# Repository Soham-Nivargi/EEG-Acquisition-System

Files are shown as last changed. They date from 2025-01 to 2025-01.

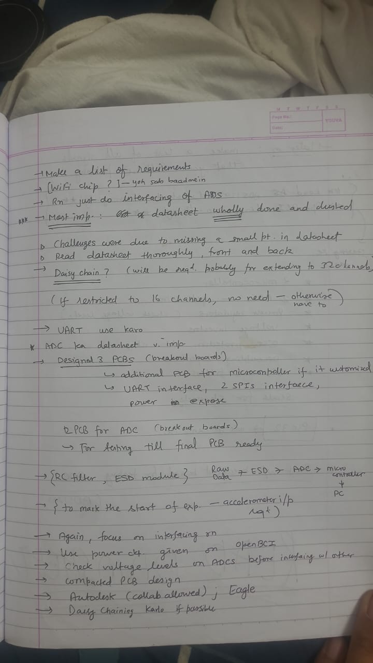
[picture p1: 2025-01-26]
Handwritten Documentation/IMG-20240304-WA0016.jpg

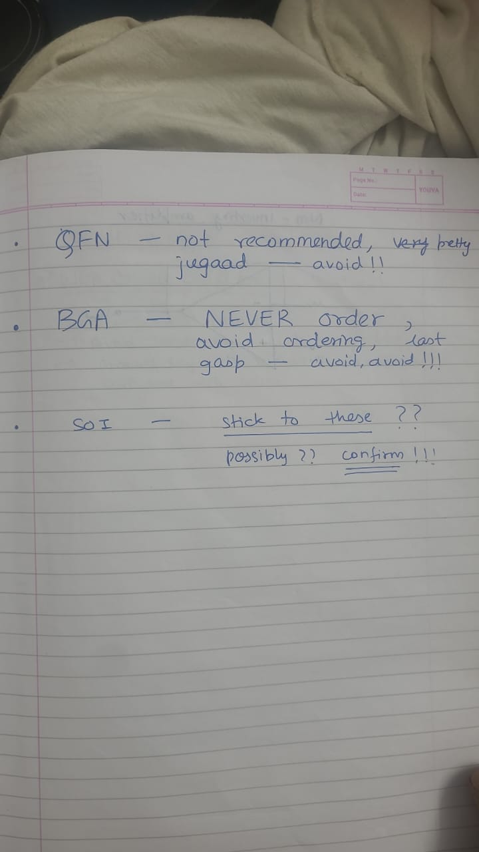
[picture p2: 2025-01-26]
Handwritten Documentation/IMG-20240304-WA0015.jpg

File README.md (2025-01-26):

# EEG-EDL-Project-Grp-14
### _This document describes the file organisation for our project - a 16 channel EEG recording system._
### Original problem statement
Primary objective of the device is to record electroencephalogram (EEG) signals from human brain with high fidelity. EEG acquisition is a non-invasive method of capturing brain signals. The device has two major parts, (a) the recording electrodes (sensors) and (b) the data capture electronics. 
In this work, we will work on developing the electronic system to capture multi-channel EEG. The term "channel" corresponds to number of electrodes (or spatial locations on the brain) that we intend to record. The primary requirement is that of recording fidelity in the presence of numerous noise sources. Noise sources in this context, mainly refers to ambient noise, one of them being the 50 Hz power-line interference. The main constraint is the form-factor of the device. 

Over the course of our project, we were forced to pivot from the original plan.

Thus, these files describe two possible implementations of a 16 channel EEG recording system.

    1. Original Plan : 16 Channels - 2 ADS1299 ICs on a single 4-layer PCB
    2. Modified Plan : 16 Channels - 2 breakout boards, each with 2 layers. Each breakout board having one ADS1299.

The files are organised as follows:

### 1. Main PCB files
   
        A. Main PCB schematic files
        B. Main PCB KiCAD project files (layout)
        
 ### 2. Breakout Board PCB files
   
        A. Breakout board PCB schematic files
        B. Breakout board PCB KiCAD project files (layout)
        C. Breakout board gerber files - for final prototype production
        
 ### 3. Intermediate schematics
   (these are building-block schematics that after being made once could be used with modifications in 
    other PCB schematics)

        A. ADS schematic
        B. ESD schematic
        C. Power Circuit schematic
        D. Bluepill schematic
        
 ### 4. Preprocessing and testing
 
        A. Code files for testing
        B. Text files with output of testing

 ### 5. Symbols and footprints 
   (contains the downloaded footprints and symbols used by us in the schematics)

 ### 6.Handwritten documentation
   (analysis of datasheets, lecture notes, discussion with professors and seniors)

 ### 7. CAD files
   (Files for 3D printing the outer casing/asssembly for our interfaced PCB)

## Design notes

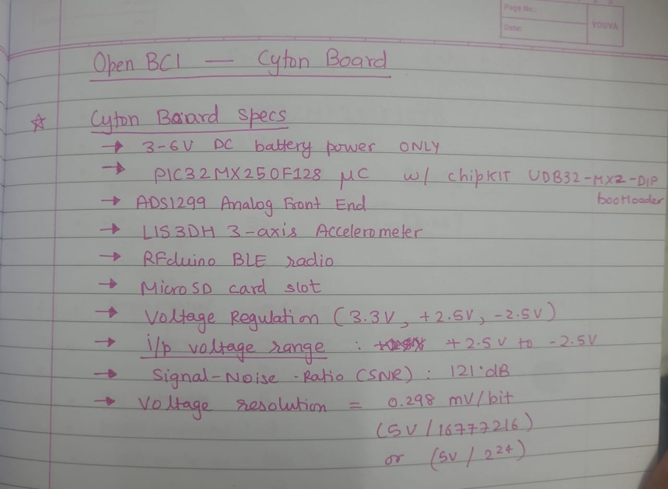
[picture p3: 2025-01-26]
Handwritten Documentation/IMG-20240304-WA0013.jpg

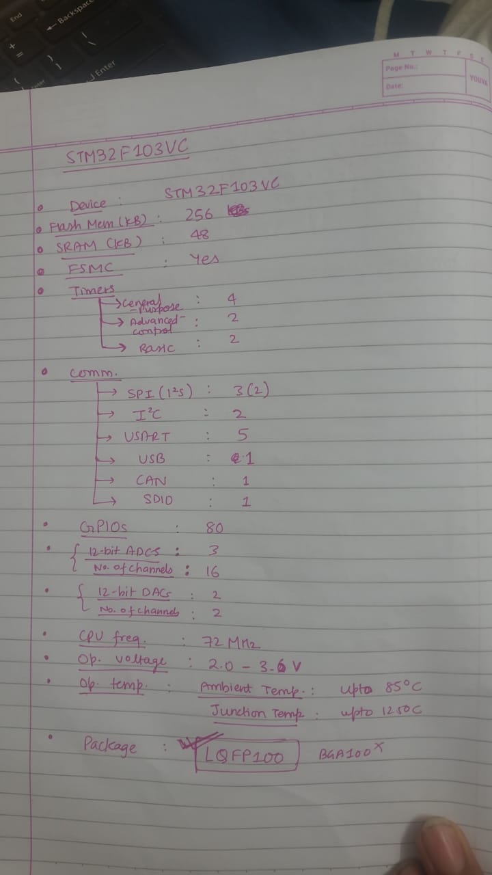
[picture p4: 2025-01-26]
Handwritten Documentation/IMG-20240304-WA0017.jpg

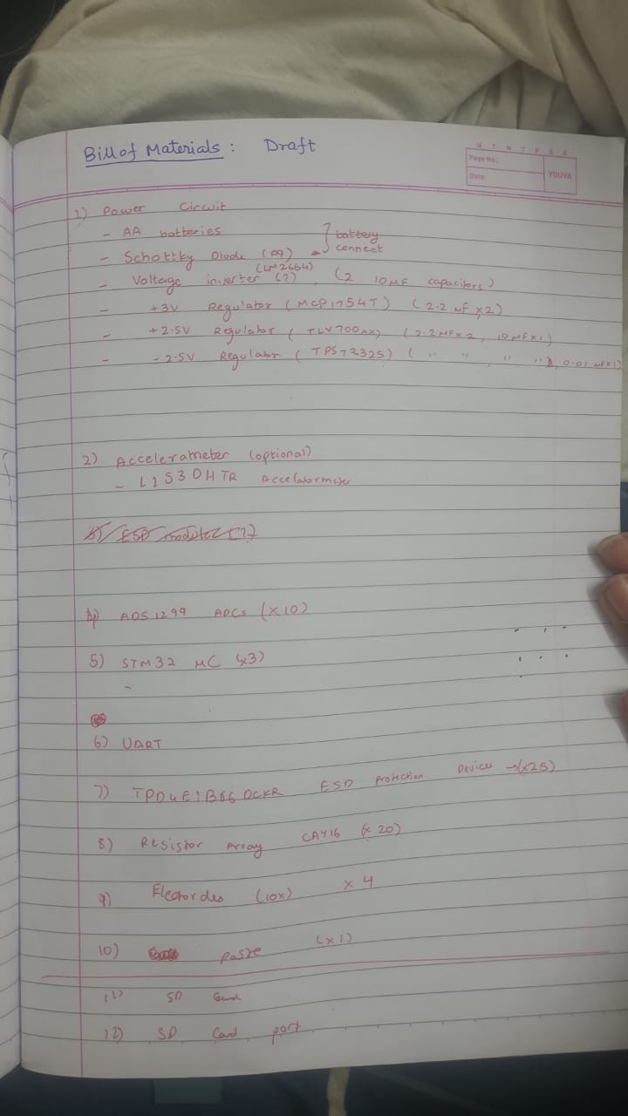
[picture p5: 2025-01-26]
Handwritten Documentation/IMG-20240304-WA0020.jpg

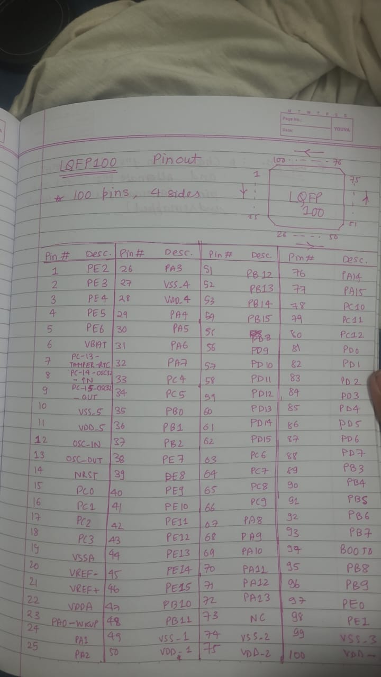
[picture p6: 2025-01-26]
Handwritten Documentation/IMG-20240304-WA0014.jpg

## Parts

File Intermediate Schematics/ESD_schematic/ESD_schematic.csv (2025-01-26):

Source: | C:\Users\91999\Downloads\hello\wien_bridge_oscillator\ESD_schematic\ESD_schematic.kicad_sch
Date: | 12-02-2024 16:13:50
Tool: | Eeschema 7.0.10
Generator: | C:\Program Files\KiCad\7.0\bin\scripting\plugins/bom_csv_grouped_by_value_with_fp.py
Component Count: | 16
Ref | Qnty | Value | Cmp name | Footprint | Description | Vendor | DNP
C1, C2, C3, C4, C6 | 5 | CKCL44X7R1H102M085AA | CKCL44X7R1H102M085AA | CKCL44X7R1H102M085AA:CAPCAF50P200X125X85-8
D1, D2, D3, D4, D5, D6 | 6 | TPD4E1B06DCKR | TPD4E1B06DCKR | TPD4E1B06DCKR:TVS_TPD4E1B06DCKR
R1, R2, R3, R4, R6 | 5 | CAY16-2201F4LF | CAY16-2201F4LF | CAY16_BRN

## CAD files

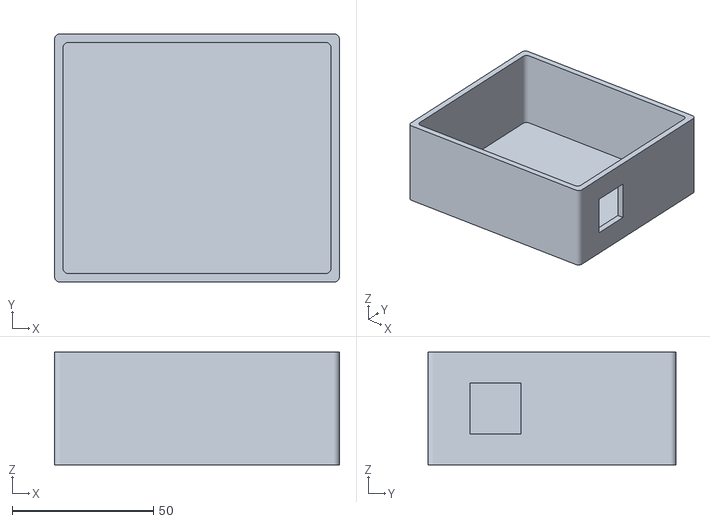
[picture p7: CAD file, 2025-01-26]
CAD files/edl_box.stl
101.0 x 88.0 x 40.0

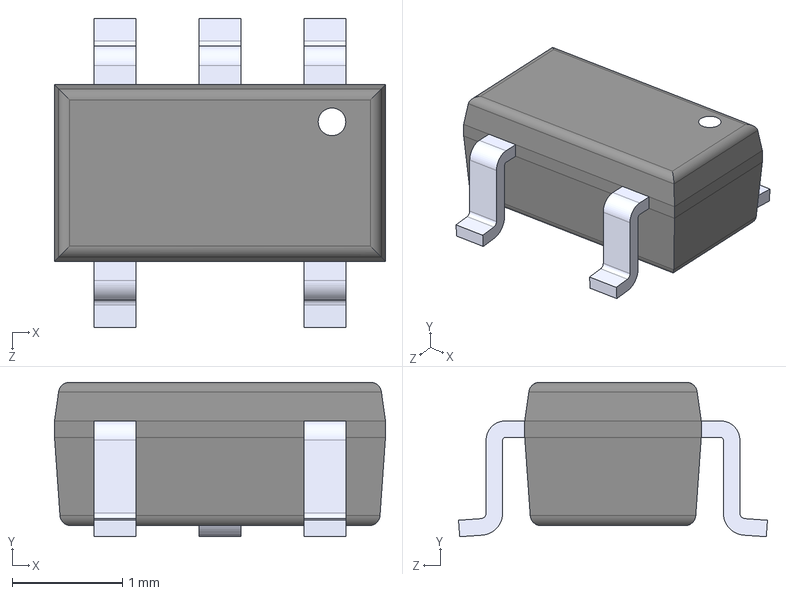
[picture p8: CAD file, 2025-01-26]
symbols_and_footprints/AP2112K - 3.3/AP2112K-3.3TRG1.step
3.00 x 1.40 x 2.80 mm

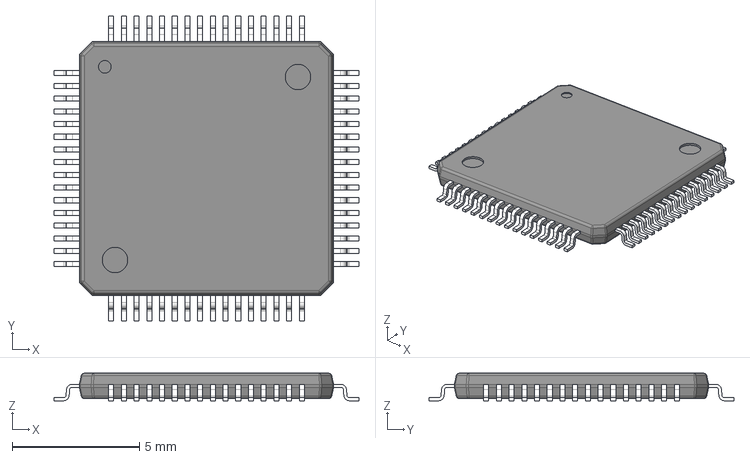
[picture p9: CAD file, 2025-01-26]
symbols_and_footprints/LIB_ADS1299IPAG/ADS1299IPAG/3D/ADS1299IPAG.stp
12.0 x 12.0 x 1.09 mm
BODY_VEC64A
LEAD_VEC64A x 64

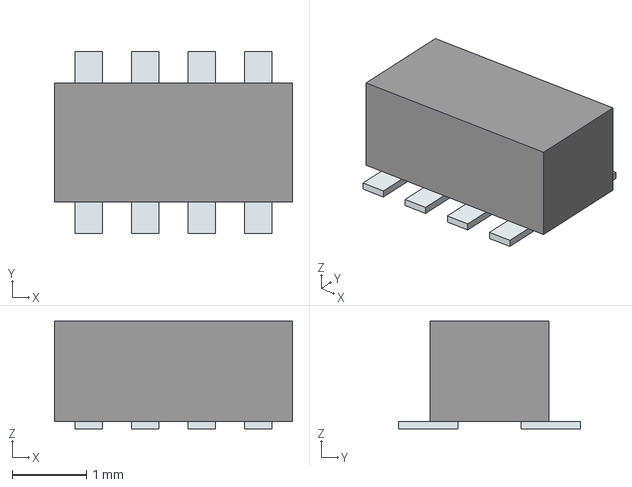
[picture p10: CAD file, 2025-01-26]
symbols_and_footprints/LIB_W3A41C102MAT2A/W3A41C102MAT2A/3D/W3A41C102MAT2A.stp
3.20 x 2.45 x 1.45 mm
Pins

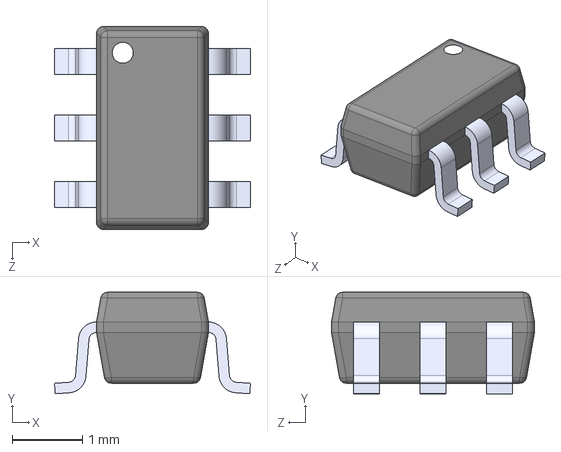
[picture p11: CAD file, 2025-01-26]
symbols_and_footprints/lm2665/LM2665M6.step
2.80 x 1.45 x 2.90 mm

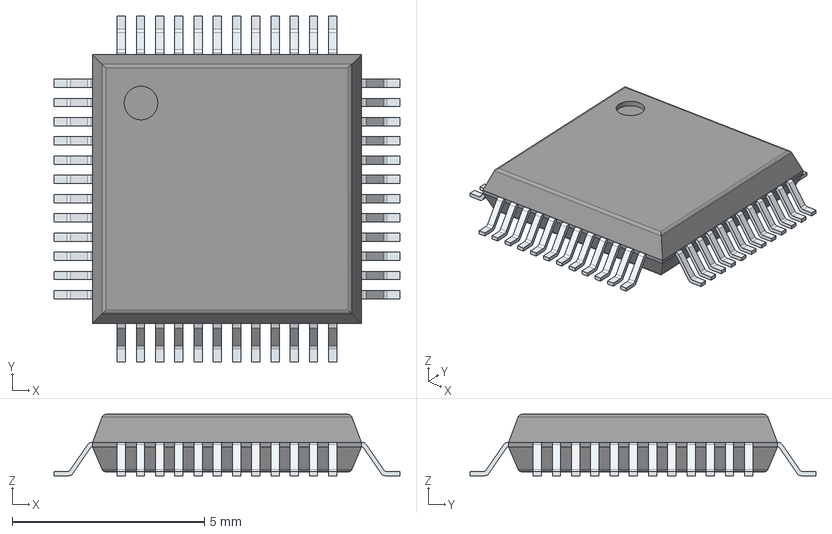
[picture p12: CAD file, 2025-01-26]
symbols_and_footprints/stm32/STM32F103C8T6TR/3D/STM32F103C8T6TR.stp
9.00 x 9.00 x 1.60 mm
PinsArrayLR
PinsArrayTB

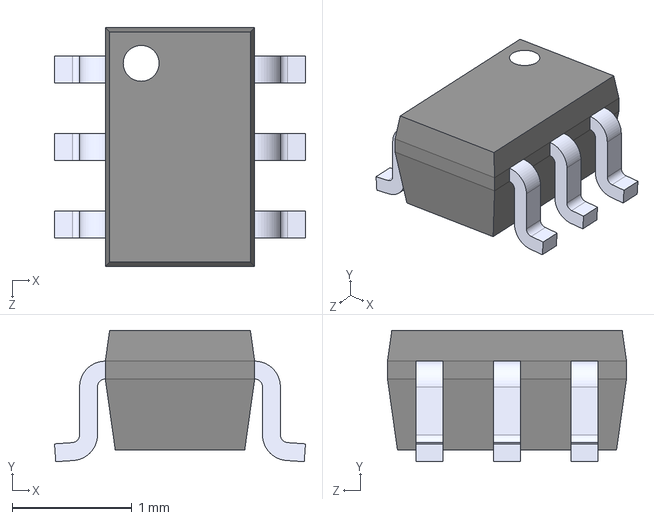
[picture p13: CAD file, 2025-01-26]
symbols_and_footprints/TPD4E1B06DCKR/TPD4E1B06DCKR.step
2.10 x 1.10 x 2.00 mm

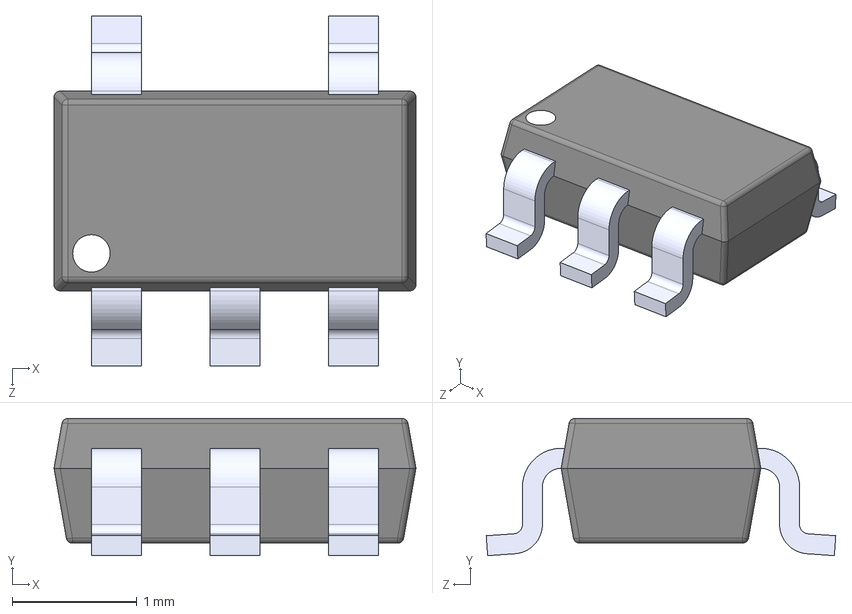
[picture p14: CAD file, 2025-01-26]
symbols_and_footprints/tlv/TLV70025QDDCRQ1.step
2.90 x 1.10 x 2.80 mm

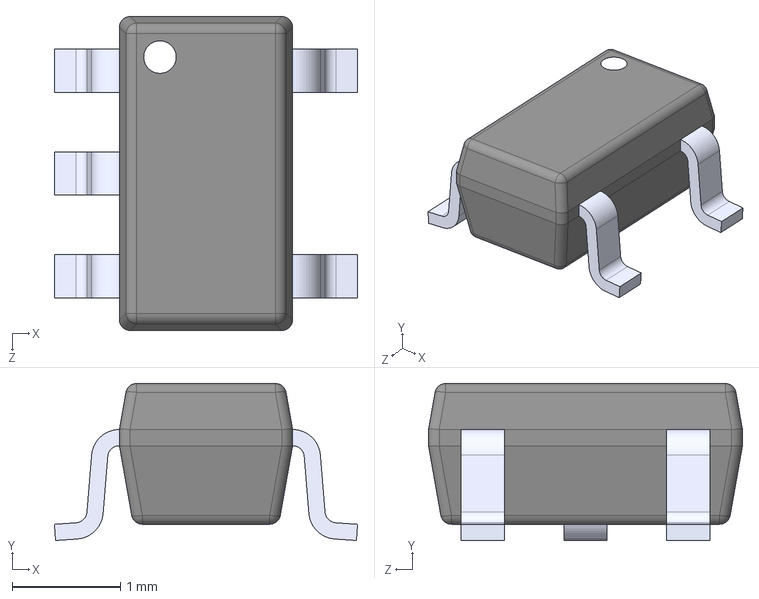
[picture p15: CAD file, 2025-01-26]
symbols_and_footprints/tps/TPS72325DBVR.step
2.80 x 1.45 x 2.90 mm

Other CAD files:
CAD files/Edl_box_.f3d
symbols_and_footprints/LIB_ADS1299IPAG/ADS1299IPAG/Allegro/qfp50p1200x1200x120-64n.psm
symbols_and_footprints/LIB_ADS1299IPAG/ADS1299IPAG/DEHDL/ads1299ipag/chips/chips.prt
symbols_and_footprints/LIB_W3A41C102MAT2A/W3A41C102MAT2A/Allegro/w3a41c102mat2a.psm
symbols_and_footprints/LIB_W3A41C102MAT2A/W3A41C102MAT2A/DEHDL/w3a41c102mat2a/chips/chips.prt
symbols_and_footprints/stm32/STM32F103C8T6TR/Allegro/qfp50p900x900x160-48n.psm
symbols_and_footprints/stm32/STM32F103C8T6TR/DEHDL/stm32f103c8t6tr/chips/chips.prt

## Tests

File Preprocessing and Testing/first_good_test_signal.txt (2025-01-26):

success12582912
81419
81596
80953
81358
81363
81739
81523
81789
success12582912
82603
82718
82394
82581
82616
82764
82656
82817
success12582912
0
8388608
8388607
8388608
8388608
0
8388608
8388608
success12582912
0
1240512
0
18
15581184
0
4845
12582912
success12582912
0
933263
8388607
9377830
0
6940615
0
8388607
success12582912
0
226513
8388607
8388608
0
13741152
0
8388607
success12582912
0
250813
8388607
8388608
0
8448695
0
8388607
success12582912
0
219410
8388607
8388608
0
8388608
0
8388607
success12582912
0
183473
8388607
8388608
0
8388608
0
8174129
success12582912
0
258539
8388607
8388608
0
8388608
0
8388607
success12582912
0
165614
8388607
8388608
0
8388608
0
8388607
success12582912
0
206816
8388607
8388800
0
3
5355391
16777088
success12582912
0
222820
8388607
8388608
0
8388608
0
8388607
success12582912
0
16648719
15887814
31836
0
16661664
0
16665404
success12582912
0
16635995
15912704
29484
0
16659882
0
16664634
success12582912
0
16641954
15906739
30159
0
16660508
0
16665207
success12582912
0
16641445
15893398
36709
0
16660210
0
16664487
success12582912
0
16650290
15898451
28247
0
16660212
0
16664377
success12582912
0
16644265
15925133
28248
0
16660806
0
16664036
success12582912
0
16635498
15923364
47761
0
16660495
0
16663225
success12582912
0
16651787
15897388
29521
0
16661507
0
16664712
success12582912
0
16647909
15861555
36088
0
16661229
0
16665673
success12582912
1382
134984
16747130
16776127
16745243
16756230
16752920
16756185
success12582922
6096
132765
16745592
0
101774
0
0
0

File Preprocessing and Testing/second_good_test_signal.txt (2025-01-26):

success12582912
81105
81345
80621
81079
81073
81491
81244
81557
success12582913
82600
82714
82401
82589
82623
82762
82652
12582913
success29360129
8388608
8388608
0
0
8388607
0
8388608
8388608
success12582912
81325
81554
80859
81289
81289
81694
81426
114688
success12582912
82618
82714
82394
82585
82623
82761
82654
114688
success12582912
98826
297766
0
14604
16629830
0
16660574
16647447
success12582912
81297
81495
80838
81234
81248
81656
81418
81692
success12582912
82546
82664
82356
82534
82572
82724
82606
82768
success12582912
82546
82664
82356
82534
82572
82724
82606
82768
success12582912
82546
82664
82356
82534
82572
82724
82606
82768
success12582912
82546
82664
82356
82534
82572
82724
82606
82768
success12582912
82546
82664
82356
82534
82572
82724
82606
82768
success12582912
82546
82664
82356
82534
82572
82724
82606
82768
success12582912
82546
82664
82356
82534
82572
82724
82606
82768
success12582912
82546
82664
82356
82534
82572
82724
82606
82768
success12582912
81340
81548
80891
81315
81313
81683
114688
317
success12582912
82603
82711
82406
82590
82633
82758
82664
82798
success12582912
0
8388608
8388607
8388608
8388608
0
8388608
8388608
success12582912
0
8388608
8388607
8388607
0
0
8388608
8388608
success12582912
0
8388608
8388607
8388607
0
0
8388608
8388608
success12582912
0
8388608
8388607
8388607
0
0
8388608
8388608
success12582912
0
12582912
0
8388608
8388607
8388607
0
0
success12582912
0
8388608
8388607
8388607
0
0
8388608
8388608
success12582912
0
8388608
8388607
8388607
0
0
8388608
8388608
success12632064
0
32768
32767
16744447
16711680
0
32768
32768
success12582912
0
8388608
8388607
8388607
0
0
8388608
8388608
success12582912
0
8388608
8387584
0
2048
2047
16775167
16773120
success12582912
8435
137108
16746079
16769675
16745474
16755648
16752532
16756418
success12582912
2081
131258
16746168
222
16745385
16756163
16752756
16756782
success12582912
9726
146843
16747320
4938
16745470
16755956
16752775
16756490
success12582912
11093
180224
15
7406088
14221187
9175007
8060803
4194220
success12582912
8449
205087
19940
624
16632658
16696934
16659447
16650415
success12582912
11593
229088
18304
1698
16632067
16696850
16659174
16649977
success12582912
4031
128496
16745359
16770377
16745504
16755925
16752667
16756270
success12582912
1609
138244
16745455
16774399
16745374
16756159
16752659
16760832
success12582912
50491
245760
194
10420967
15007796
8323197
1474559
16740717
success12582912
47397
184217
3504
23639
8388607
7433478
0
16754759
success12582912
51818
191748
6921
29670
8388607
7433491
49152
0

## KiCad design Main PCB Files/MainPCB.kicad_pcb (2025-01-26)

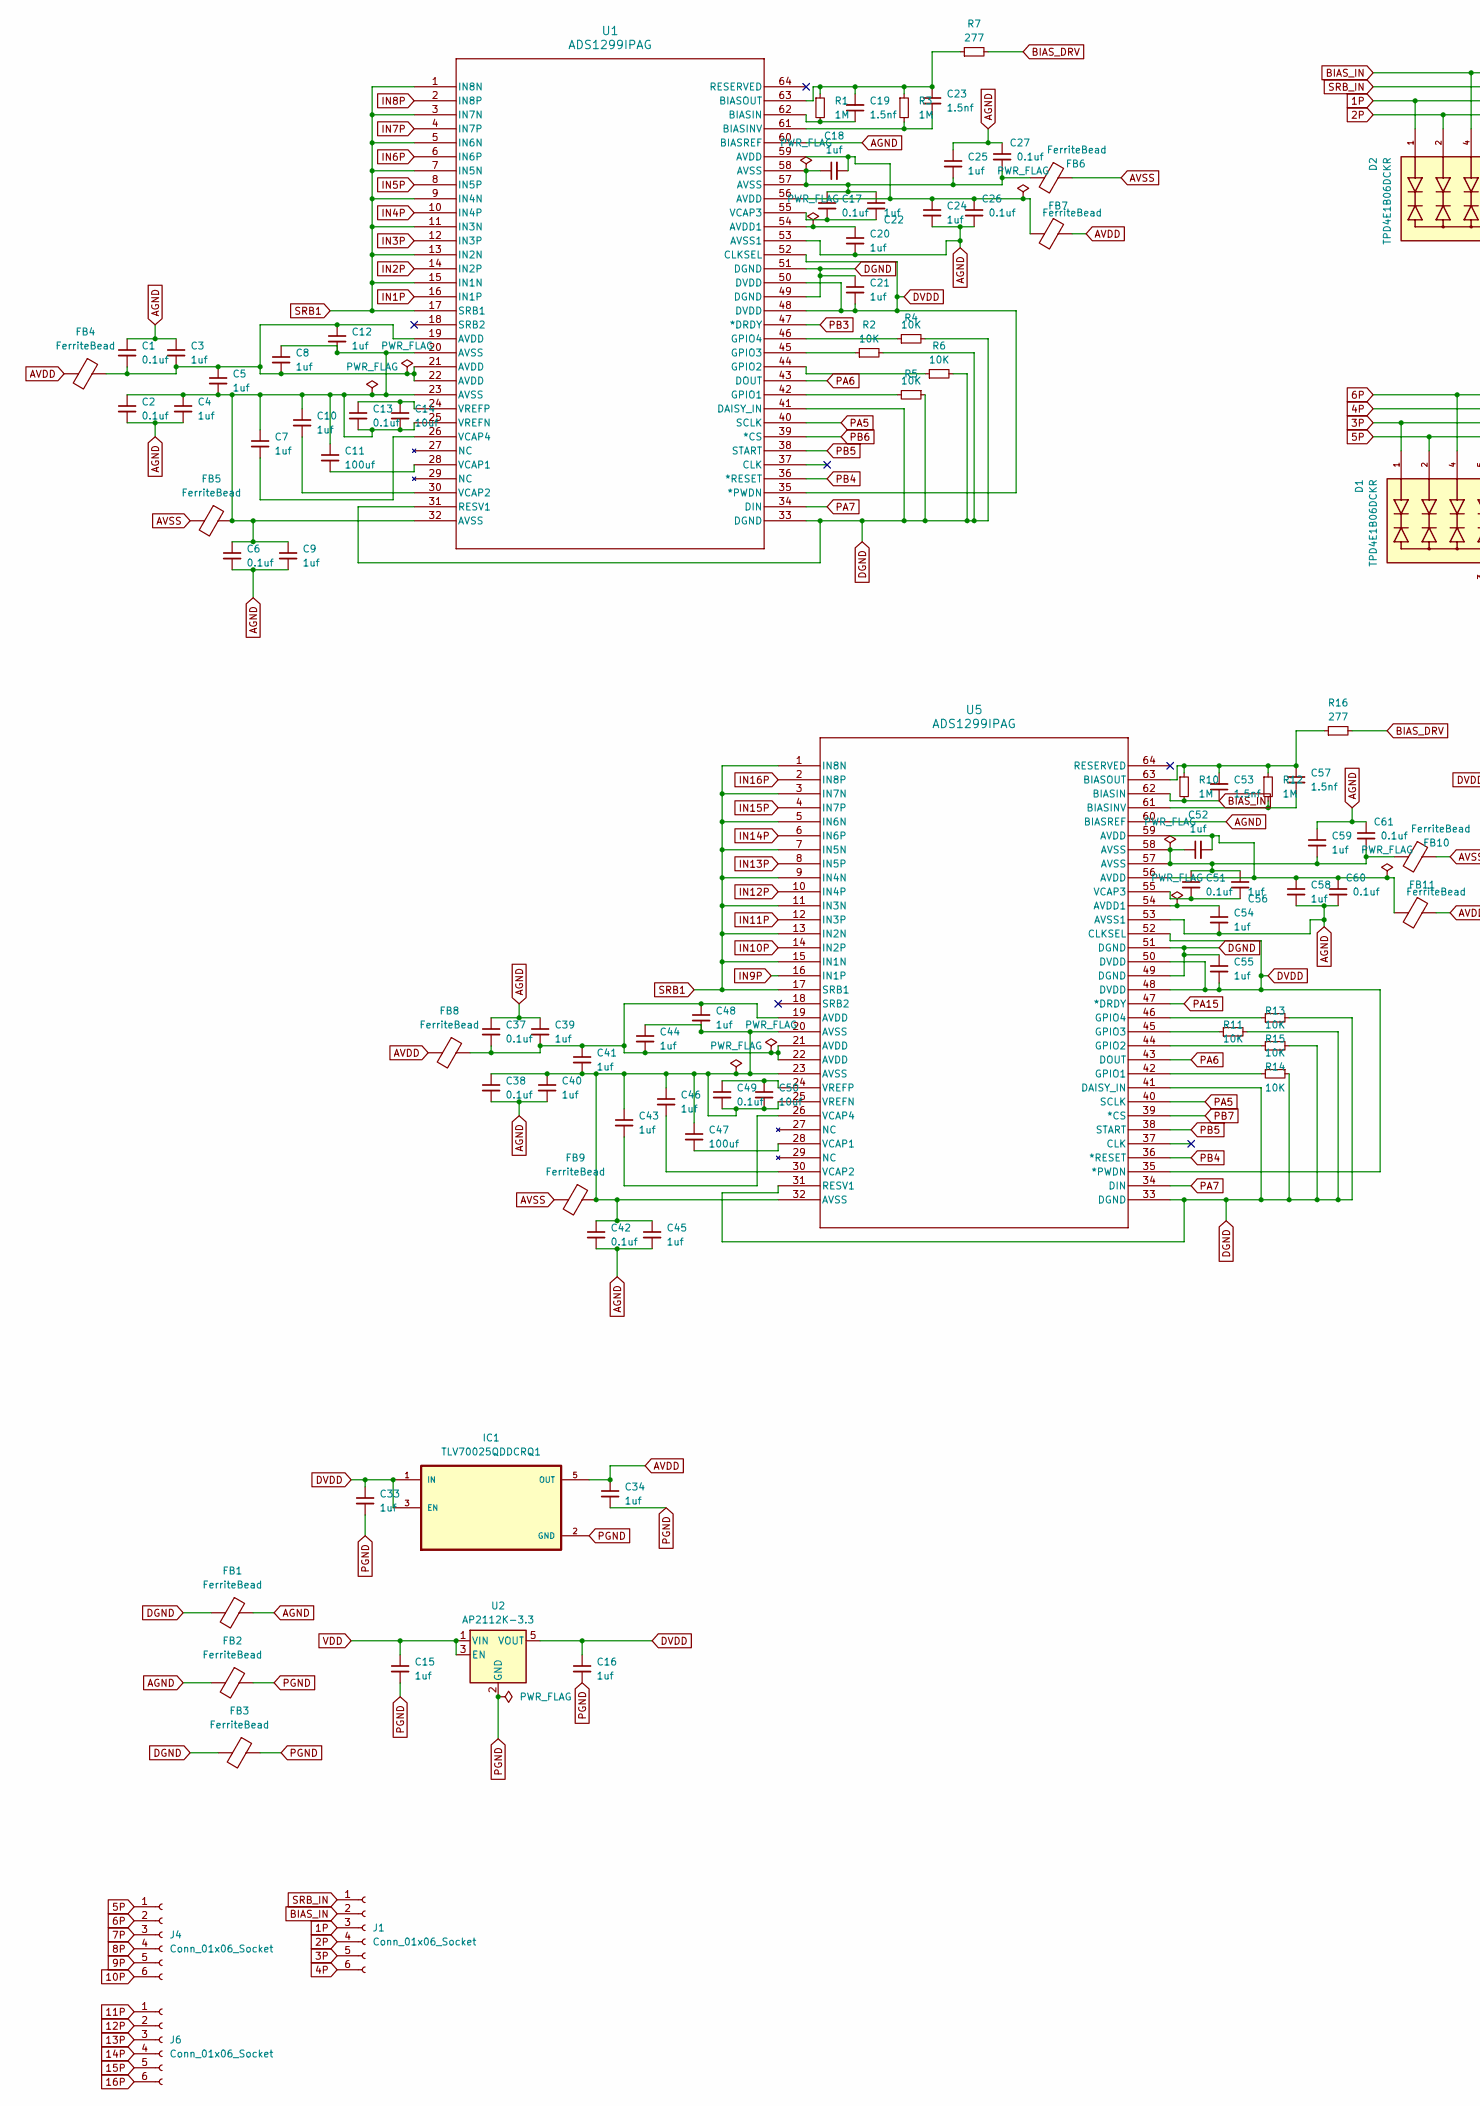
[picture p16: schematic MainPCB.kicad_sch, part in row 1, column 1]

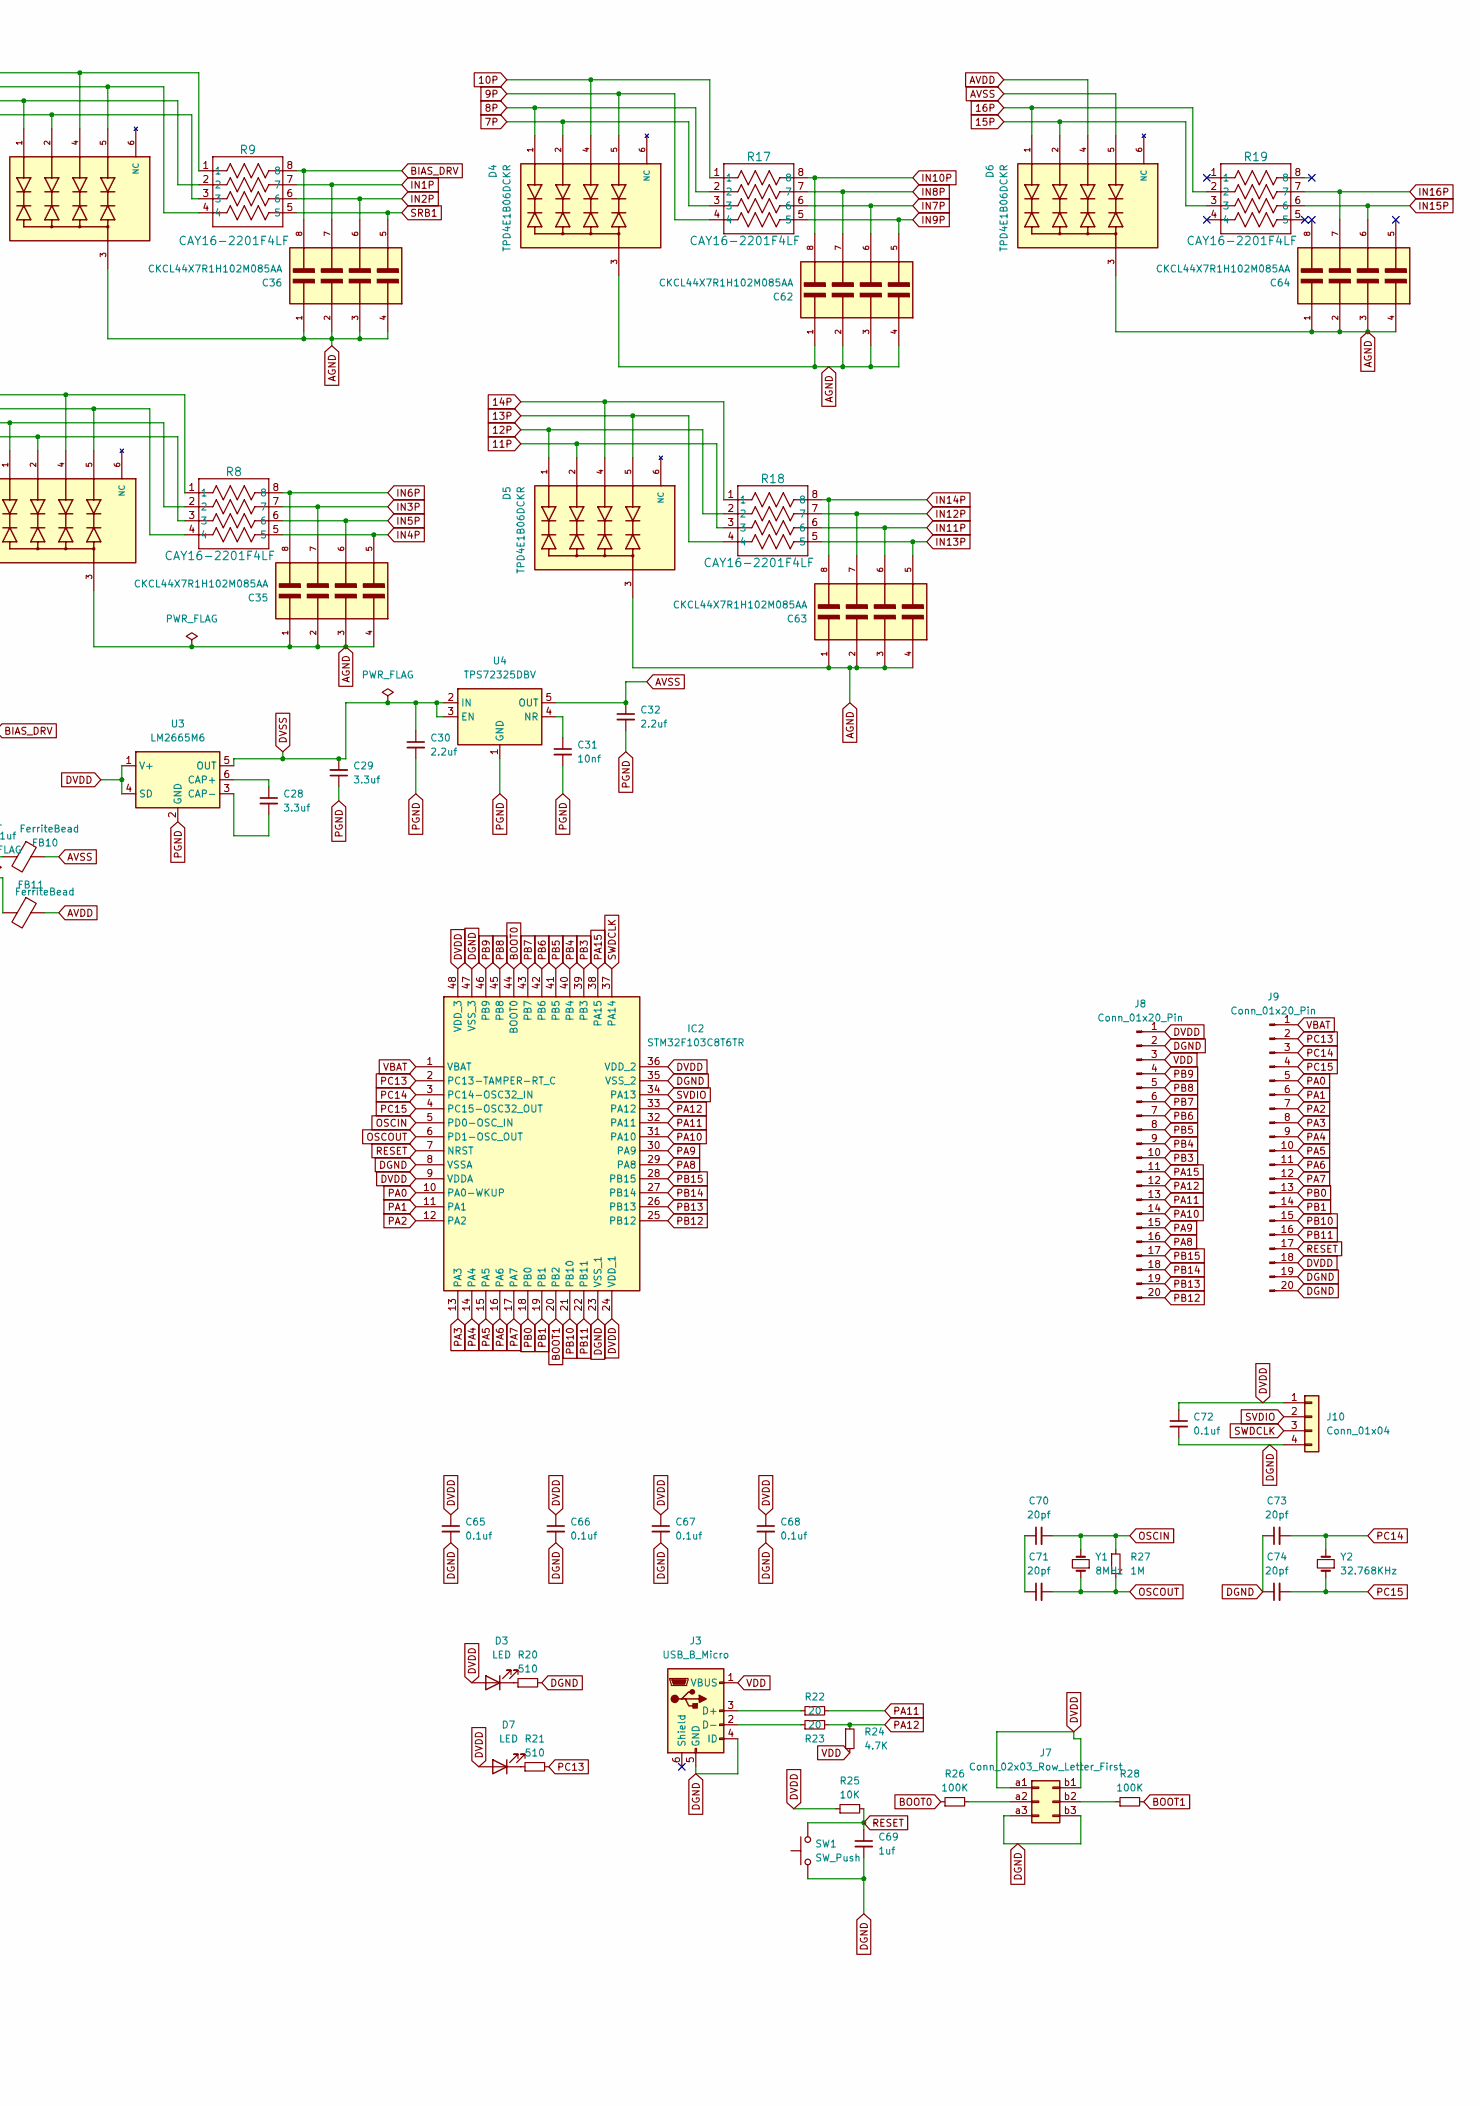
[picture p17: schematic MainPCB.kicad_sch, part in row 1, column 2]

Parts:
C1, C2, C6, C13, C17, C26, C27, C37, C38, C42, C49, C51, C60, C61, C65, C66, C67, C68, C72: 0.1uf; C_0603_1608Metric_Pad1.08x0.95mm_HandSolder
C3, C4, C5, C7, C8, C9, C10, C12, C15, C16, C18, C20, C21, C22, C24, C25, C33, C34, C39, C40, C41, C43, C44, C45, C46, C48, C52, C54, C55, C56, C58, C59, C69: 1uf; C_0603_1608Metric_Pad1.08x0.95mm_HandSolder
C11, C47: 100uf; C_1206_3216Metric_Pad1.33x1.80mm_HandSolder
C14, C50: 10uf; CP_EIA-3216-18_Kemet-A_Pad1.58x1.35mm_HandSolder
C19, C23, C53, C57: 1.5nf; C_0603_1608Metric_Pad1.08x0.95mm_HandSolder
C28, C29: 3.3uf; CP_EIA-3216-18_Kemet-A_Pad1.58x1.35mm_HandSolder
C30, C32: 2.2uf; C_0603_1608Metric_Pad1.08x0.95mm_HandSolder
C31: 10nf; C_0603_1608Metric_Pad1.08x0.95mm_HandSolder
C35, C36, C62, C63, C64: CKCL44X7R1H102M085AA; W3A41C102MAT2A; PARTREV Dec 2014
C70, C71, C73, C74: 20pf; C_0603_1608Metric_Pad1.08x0.95mm_HandSolder
D1, D2, D4, D5, D6: TPD4E1B06DCKR; TVS_TPD4E1B06DCKR; PARTREV C
D3, D7: LED; LED_0402_1005Metric_Pad0.77x0.64mm_HandSolder
FB1, FB2, FB3, FB4, FB5, FB6, FB7, FB8, FB9, FB10, FB11: FerriteBead; L_0603_1608Metric_Pad1.05x0.95mm_HandSolder
IC1: TLV70025QDDCRQ1; SOT95P280X110-5N
IC2: STM32F103C8T6TR; QFP50P900X900X160-48N; Mouser Part Number 511-STM32F103C8T6TR
J1, J4, J6: Conn_01x06_Socket; PinSocket_1x06_P2.54mm_Vertical
J3: USB_B_Micro; USB_Micro-B_Molex_47346-0001
J7: Conn_02x03_Row_Letter_First; PinHeader_2x03_P2.54mm_Vertical
J8, J9: Conn_01x20_Pin; PinHeader_1x20_P2.54mm_Vertical
J10: Conn_01x04; PinHeader_1x04_P2.54mm_Vertical
R1, R3, R10, R12, R27: 1M; R_0603_1608Metric_Pad0.98x0.95mm_HandSolder
R2, R4, R5, R6, R11, R13, R14, R15, R25: 10K; R_0603_1608Metric_Pad0.98x0.95mm_HandSolder
R7, R16: 277; R_0603_1608Metric_Pad0.98x0.95mm_HandSolder
R8, R9, R17, R18, R19: CAY16-2201F4LF; CAY16_BRN
R20, R21: 510; R_0603_1608Metric_Pad0.98x0.95mm_HandSolder
R22, R23: 20; R_0603_1608Metric_Pad0.98x0.95mm_HandSolder
R24: 4.7K; R_0603_1608Metric_Pad0.98x0.95mm_HandSolder
R26, R28: 100K; R_0603_1608Metric_Pad0.98x0.95mm_HandSolder
SW1: SW_Push; SW_SPST_TL3342
U1, U5: ADS1299IPAG; QFP50P1200X1200X120-64N
U2: AP2112K-3.3; SOT95P285X140-5N
U3: LM2665M6; SOT95P280X145-6N
U4: TPS72325DBV; SOT95P280X145-5N
Y1: 8MHz; Crystal_HC50_Vertical
Y2: 32.768KHz; 830016178

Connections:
1P: D2.1, J1.3, R9.2
2P: D2.2, J1.4, R9.3
3P: D1.1, J1.5, R8.2
4P: D1.5, J1.6, R8.4
5P: D1.2, J4.1, R8.3
6P: D1.4, J4.2, R8.1
7P: D4.2, J4.3, R17.3
8P: D4.1, J4.4, R17.2
9P: D4.5, J4.5, R17.4
10P: D4.4, J4.6, R17.1
11P: D5.2, J6.1, R18.3
12P: D5.1, J6.2, R18.2
13P: D5.5, J6.3, R18.4
14P: D5.4, J6.4, R18.1
15P: D6.2, J6.5, R19.3
16P: D6.1, J6.6, R19.2
AGND: C1.1, C2.2, C3.1, C4.2, C6.2, C9.2, C20.2, C24.2, C25.1, C26.2, C27.1, C35.1, C35.2, C35.3, C35.4, C36.1, C36.2, C36.3, C36.4, C37.1, C38.2, C39.1, C40.2, C42.2, C45.2, C54.2, C58.2, C59.1, C60.2, C61.1, C62.1, C62.2, C62.3, C62.4, C63.1, C63.2, C63.3, C63.4, C64.1, C64.2, C64.3, C64.4, D1.3, D2.3, D4.3, D5.3, D6.3, FB1.1, FB2.2, U1.53 (AVSS1), U1.60 (BIASREF), U5.53 (AVSS1), U5.60 (BIASREF)
AVDD: C34.1, D6.4, FB4.2, FB7.1, FB8.2, FB11.1, IC1.5 (OUT)
AVSS: C32.1, D6.5, FB5.2, FB6.1, FB9.2, FB10.1, U4.5 (OUT)
BIAS_DRV: C36.8, R7.2, R9.8, R16.2
BIAS_IN: C53.1, D2.4, J1.2, R9.1, R10.2, U5.62 (BIASIN)
BOOT0: IC2.44 (BOOT0), R26.1
BOOT1: IC2.20 (PB2), R28.2
DGND: C21.1, C55.1, C65.2, C66.2, C67.2, C68.2, C69.2, C72.2, C73.1, C74.1, FB1.2, FB3.2, IC2.8 (VSSA), IC2.23 (VSS_1), IC2.35 (VSS_2), IC2.47 (VSS_3), J3.4 (ID), J3.5 (GND), J7.a3, J7.b3, J8.2, J9.19, J9.20, J10.4, R2.2, R4.2, R5.1, R6.2, R11.2, R13.2, R14.1, R15.2, R20.2, SW1.1, U1.31 (RESV1), U1.33 (DGND), U1.41 (DAISY_IN), U1.49 (DGND), U1.51 (DGND), U5.31 (RESV1), U5.33 (DGND), U5.41 (DAISY_IN), U5.49 (DGND), U5.51 (DGND)
DVDD: C16.1, C21.2, C33.1, C55.2, C65.1, C66.1, C67.1, C68.1, C72.1, D3.2 (A), D7.2 (A), IC1.1 (IN), IC1.3 (EN), IC2.9 (VDDA), IC2.24 (VDD_1), IC2.36 (VDD_2), IC2.48 (VDD_3), J7.a1, J7.b1, J8.1, J9.18, J10.1, R25.1, U1.35 (*PWDN), U1.48 (DVDD), U1.50 (DVDD), U1.52 (CLKSEL), U2.5 (VOUT), U3.1 (V+), U3.4 (SD), U5.35 (*PWDN), U5.48 (DVDD), U5.50 (DVDD), U5.52 (CLKSEL)
DVSS: C29.2, C30.1, U3.5 (OUT), U4.2 (IN), U4.3 (EN)
IN1P: C36.7, R9.7, U1.16 (IN1P)
IN2P: C36.6, R9.6, U1.14 (IN2P)
IN3P: C35.7, R8.7, U1.12 (IN3P)
IN4P: C35.5, R8.5, U1.10 (IN4P)
IN5P: C35.6, R8.6, U1.8 (IN5P)
IN6P: C35.8, R8.8, U1.6 (IN6P)
IN7P: C62.6, R17.6, U1.4 (IN7P)
IN8P: C62.7, R17.7, U1.2 (IN8P)
IN9P: C62.5, R17.5, U5.16 (IN1P)
IN10P: C62.8, R17.8, U5.14 (IN2P)
IN11P: C63.6, R18.6, U5.12 (IN3P)
IN12P: C63.7, R18.7, U5.10 (IN4P)
IN13P: C63.5, R18.5, U5.8 (IN5P)
IN14P: C63.8, R18.8, U5.6 (IN6P)
IN15P: C64.6, R19.6, U5.4 (IN7P)
IN16P: C64.7, R19.7, U5.2 (IN8P)
unnamed: C1.2, C3.2, C5.1, C8.2, C12.1, FB4.1, U1.19 (AVDD), U1.21 (AVDD), U1.22 (AVDD)
unnamed: C17.1, C18.1, C22.1, C25.2, C27.2, FB6.2, U1.57 (AVSS), U1.58 (AVSS)
unnamed: C18.2, C24.1, C26.1, FB7.2, U1.56 (AVDD), U1.59 (AVDD)
unnamed: C37.2, C39.2, C41.1, C44.2, C48.1, FB8.1, U5.19 (AVDD), U5.21 (AVDD), U5.22 (AVDD)
unnamed: C51.1, C52.1, C56.1, C59.2, C61.2, FB10.2, U5.57 (AVSS), U5.58 (AVSS)
unnamed: C52.2, C58.1, C60.1, FB11.2, U5.56 (AVDD), U5.59 (AVDD)
unnamed: C70.1, C71.1
unnamed: D3.1 (K), R20.1
unnamed: D7.1 (K), R21.1
unnamed: J3.3 (D+), R22.1
unnamed: J3.2 (D-), R23.1
unnamed: J7.a2, R26.2
unnamed: J7.b2, R28.1
unnamed: C20.1, U1.54 (AVDD1)
unnamed: C19.1, R1.2, U1.62 (BIASIN)
unnamed: C23.2, R3.2, U1.61 (BIASINV)
unnamed: C19.2, C23.1, R1.1, R3.1, R7.1, U1.63 (BIASOUT)
unnamed: R5.2, U1.42 (GPIO1)
unnamed: R6.1, U1.44 (GPIO2)
unnamed: R2.1, U1.45 (GPIO3)
unnamed: R4.1, U1.46 (GPIO4)
unnamed: C11.2, U1.28 (VCAP1)
unnamed: C10.2, U1.30 (VCAP2)
unnamed: C17.2, C22.2, U1.55 (VCAP3)
unnamed: C7.2, U1.26 (VCAP4)
unnamed: C2.1, C4.1, C5.2, C6.1, C7.1, C8.1, C9.1, C10.1, C11.1, C12.2, C13.2, C14.2, FB5.1, U1.20 (AVSS), U1.23 (AVSS), U1.25 (VREFN), U1.32 (AVSS)
unnamed: C13.1, C14.1, U1.24 (VREFP)
unnamed: C28.1, U3.6 (CAP+)
unnamed: C28.2, U3.3 (CAP-)
unnamed: C31.1, U4.4 (NR)
unnamed: C54.1, U5.54 (AVDD1)
unnamed: C57.2, R12.2, U5.61 (BIASINV)
unnamed: C53.2, C57.1, R10.1, R12.1, R16.1, U5.63 (BIASOUT)
unnamed: R14.2, U5.42 (GPIO1)
unnamed: R15.1, U5.44 (GPIO2)
unnamed: R11.1, U5.45 (GPIO3)
unnamed: R13.1, U5.46 (GPIO4)
unnamed: C47.2, U5.28 (VCAP1)
unnamed: C46.2, U5.30 (VCAP2)
unnamed: C51.2, C56.2, U5.55 (VCAP3)
unnamed: C43.2, U5.26 (VCAP4)
unnamed: C38.1, C40.1, C41.2, C42.1, C43.1, C44.1, C45.1, C46.1, C47.1, C48.2, C49.2, C50.2, FB9.1, U5.20 (AVSS), U5.23 (AVSS), U5.25 (VREFN), U5.32 (AVSS)
unnamed: C49.1, C50.1, U5.24 (VREFP)
OSCIN: C70.2, IC2.5 (PD0-OSC_IN), R27.1, Y1.2
OSCOUT: C71.2, IC2.6 (PD1-OSC_OUT), R27.2, Y1.1
PA0: IC2.10 (PA0-WKUP), J9.5
PA1: IC2.11 (PA1), J9.6
PA2: IC2.12 (PA2), J9.7
PA3: IC2.13 (PA3), J9.8
PA4: IC2.14 (PA4), J9.9
PA5: IC2.15 (PA5), J9.10, U1.40 (SCLK), U5.40 (SCLK)
PA6: IC2.16 (PA6), J9.11, U1.43 (DOUT), U5.43 (DOUT)
PA7: IC2.17 (PA7), J9.12, U1.34 (DIN), U5.34 (DIN)
PA8: IC2.29 (PA8), J8.16
PA9: IC2.30 (PA9), J8.15
PA10: IC2.31 (PA10), J8.14
PA11: IC2.32 (PA11), J8.13, R22.2
PA12: IC2.33 (PA12), J8.12, R23.2, R24.1
PA15: IC2.38 (PA15), J8.11, U5.47 (*DRDY)
PB0: IC2.18 (PB0), J9.13
PB1: IC2.19 (PB1), J9.14
PB3: IC2.39 (PB3), J8.10, U1.47 (*DRDY)
PB4: IC2.40 (PB4), J8.9, U1.36 (*RESET), U5.36 (*RESET)
PB5: IC2.41 (PB5), J8.8, U1.38 (START), U5.38 (START)
PB6: IC2.42 (PB6), J8.7, U1.39 (*CS)
PB7: IC2.43 (PB7), J8.6, U5.39 (*CS)
PB8: IC2.45 (PB8), J8.5
PB9: IC2.46 (PB9), J8.4
PB10: IC2.21 (PB10), J9.15
PB11: IC2.22 (PB11), J9.16
PB12: IC2.25 (PB12), J8.20
PB13: IC2.26 (PB13), J8.19
PB14: IC2.27 (PB14), J8.18
PB15: IC2.28 (PB15), J8.17
PC13: IC2.2 (PC13-TAMPER-RT_C), J9.2, R21.2
PC14: C73.2, IC2.3 (PC14-OSC32_IN), J9.3, Y2.2
PC15: C74.2, IC2.4 (PC15-OSC32_OUT), J9.4, Y2.1
PGND: C15.2, C16.2, C29.1, C30.2, C31.2, C32.2, C33.2, C34.2, FB2.1, FB3.1, IC1.2 (GND), U2.2 (GND), U3.2 (GND), U4.1 (GND)
RESET: C69.1, IC2.7 (NRST), J9.17, R25.2, SW1.2
SRB1: C36.5, R9.5, U1.1 (IN8N), U1.3 (IN7N), U1.5 (IN6N), U1.7 (IN5N), U1.9 (IN4N), U1.11 (IN3N), U1.13 (IN2N), U1.15 (IN1N), U1.17 (SRB1), U5.1 (IN8N), U5.3 (IN7N), U5.5 (IN6N), U5.7 (IN5N), U5.9 (IN4N), U5.11 (IN3N), U5.13 (IN2N), U5.15 (IN1N), U5.17 (SRB1)
SRB_IN: D2.5, J1.1, R9.4
SVDIO: IC2.34 (PA13), J10.2
SWDCLK: IC2.37 (PA14), J10.3
VBAT: IC2.1 (VBAT), J9.1
VDD: C15.1, J3.1 (VBUS), J8.3, R24.2, U2.1 (VIN), U2.3 (EN)

Board: 4 copper layers, 138 parts (38 on the bottom side), 125 nets, no tracks yet.

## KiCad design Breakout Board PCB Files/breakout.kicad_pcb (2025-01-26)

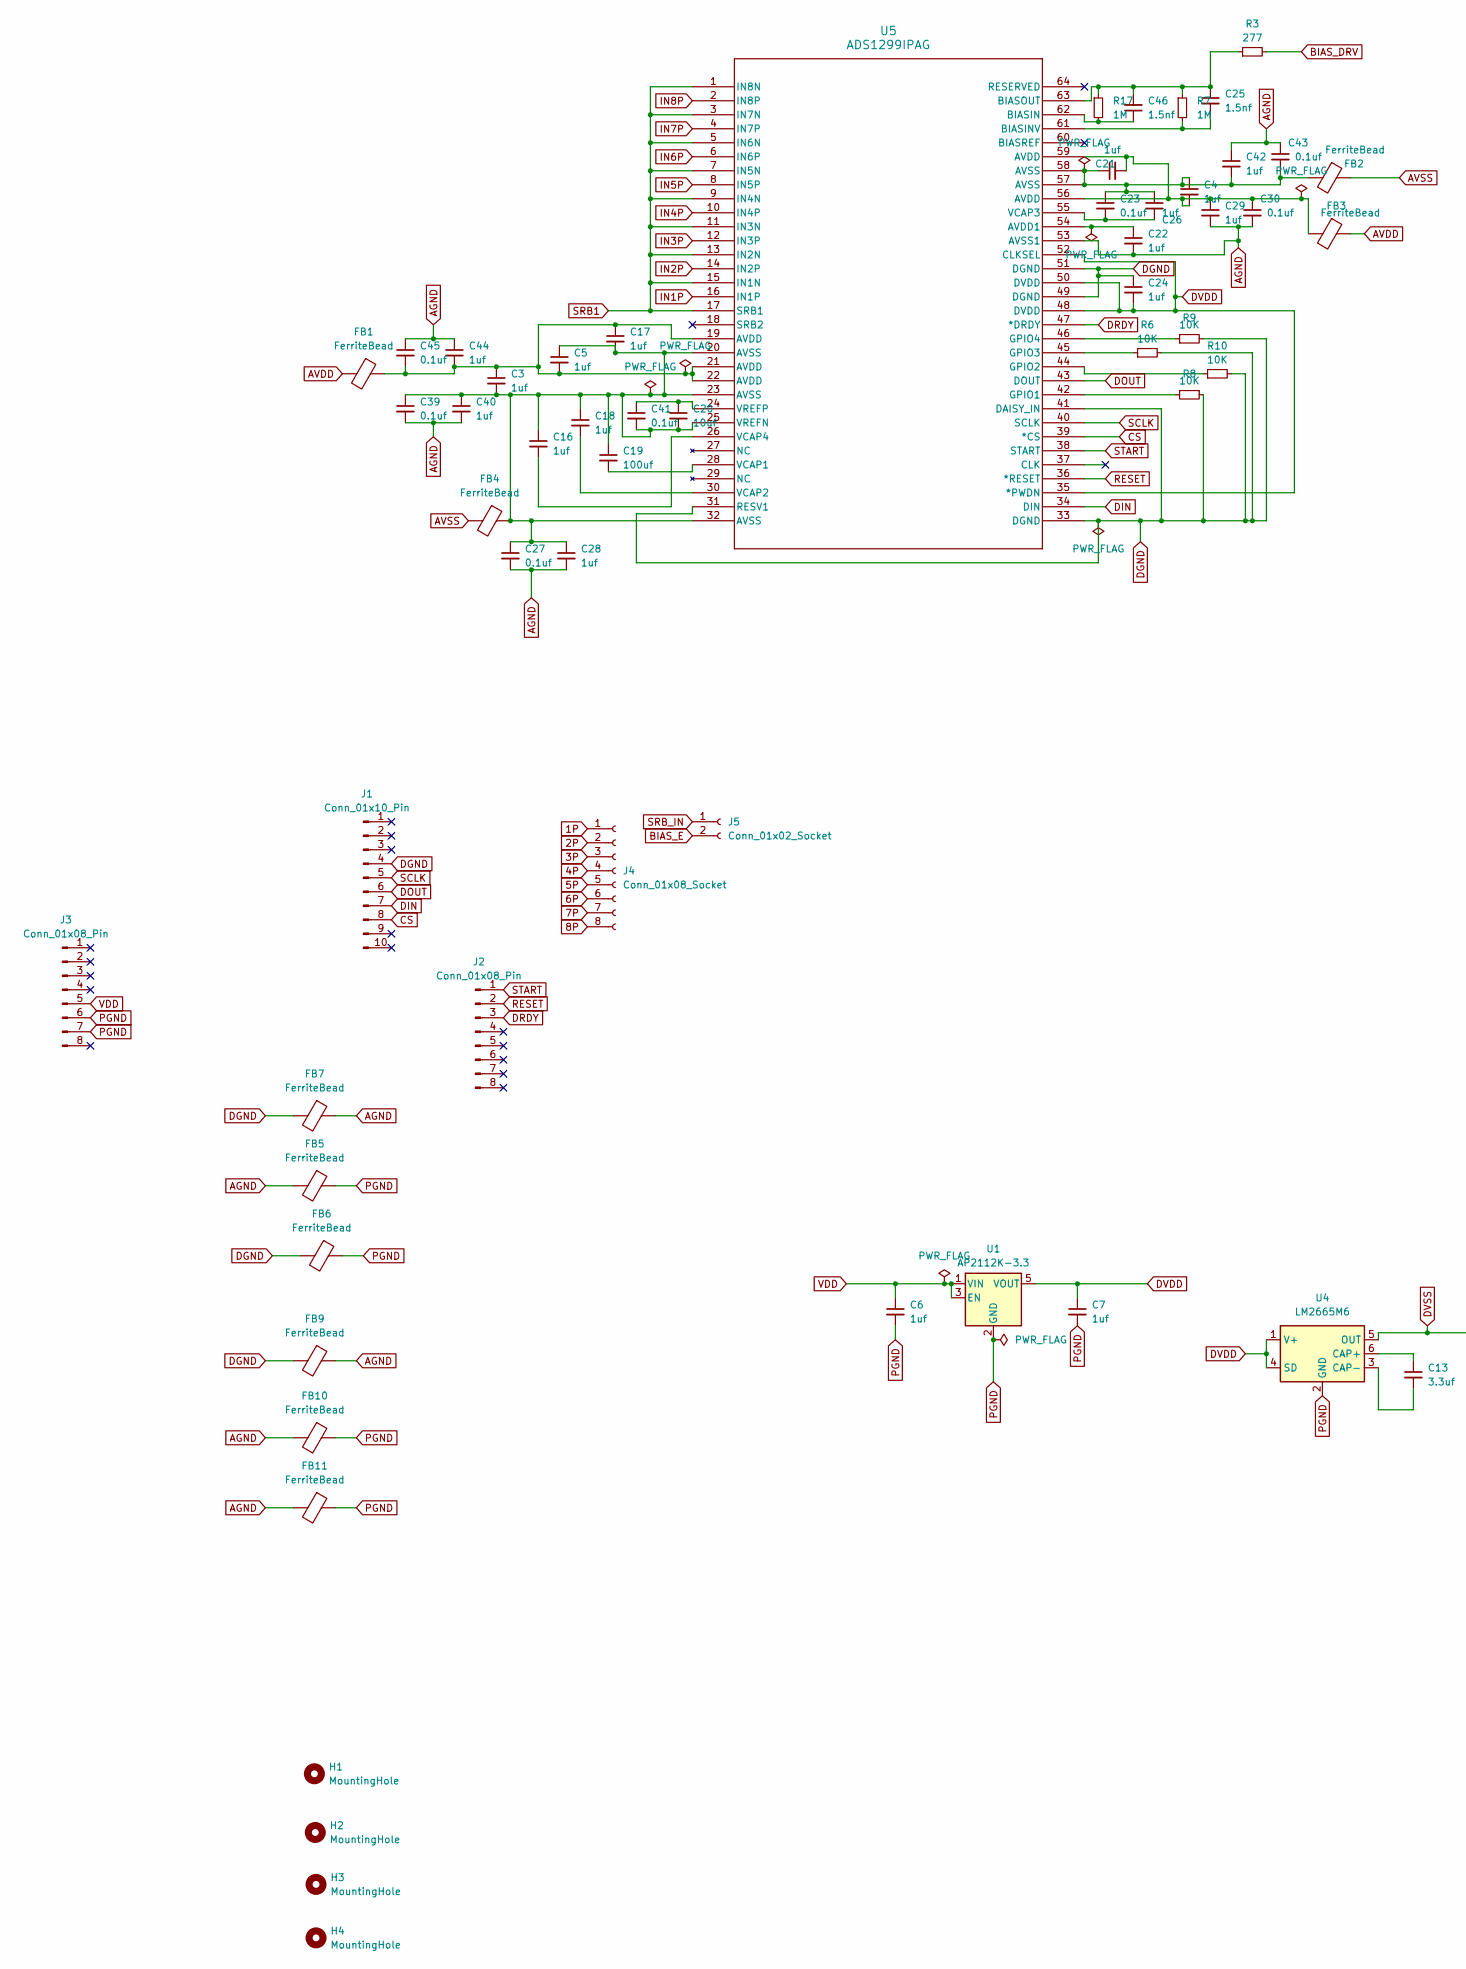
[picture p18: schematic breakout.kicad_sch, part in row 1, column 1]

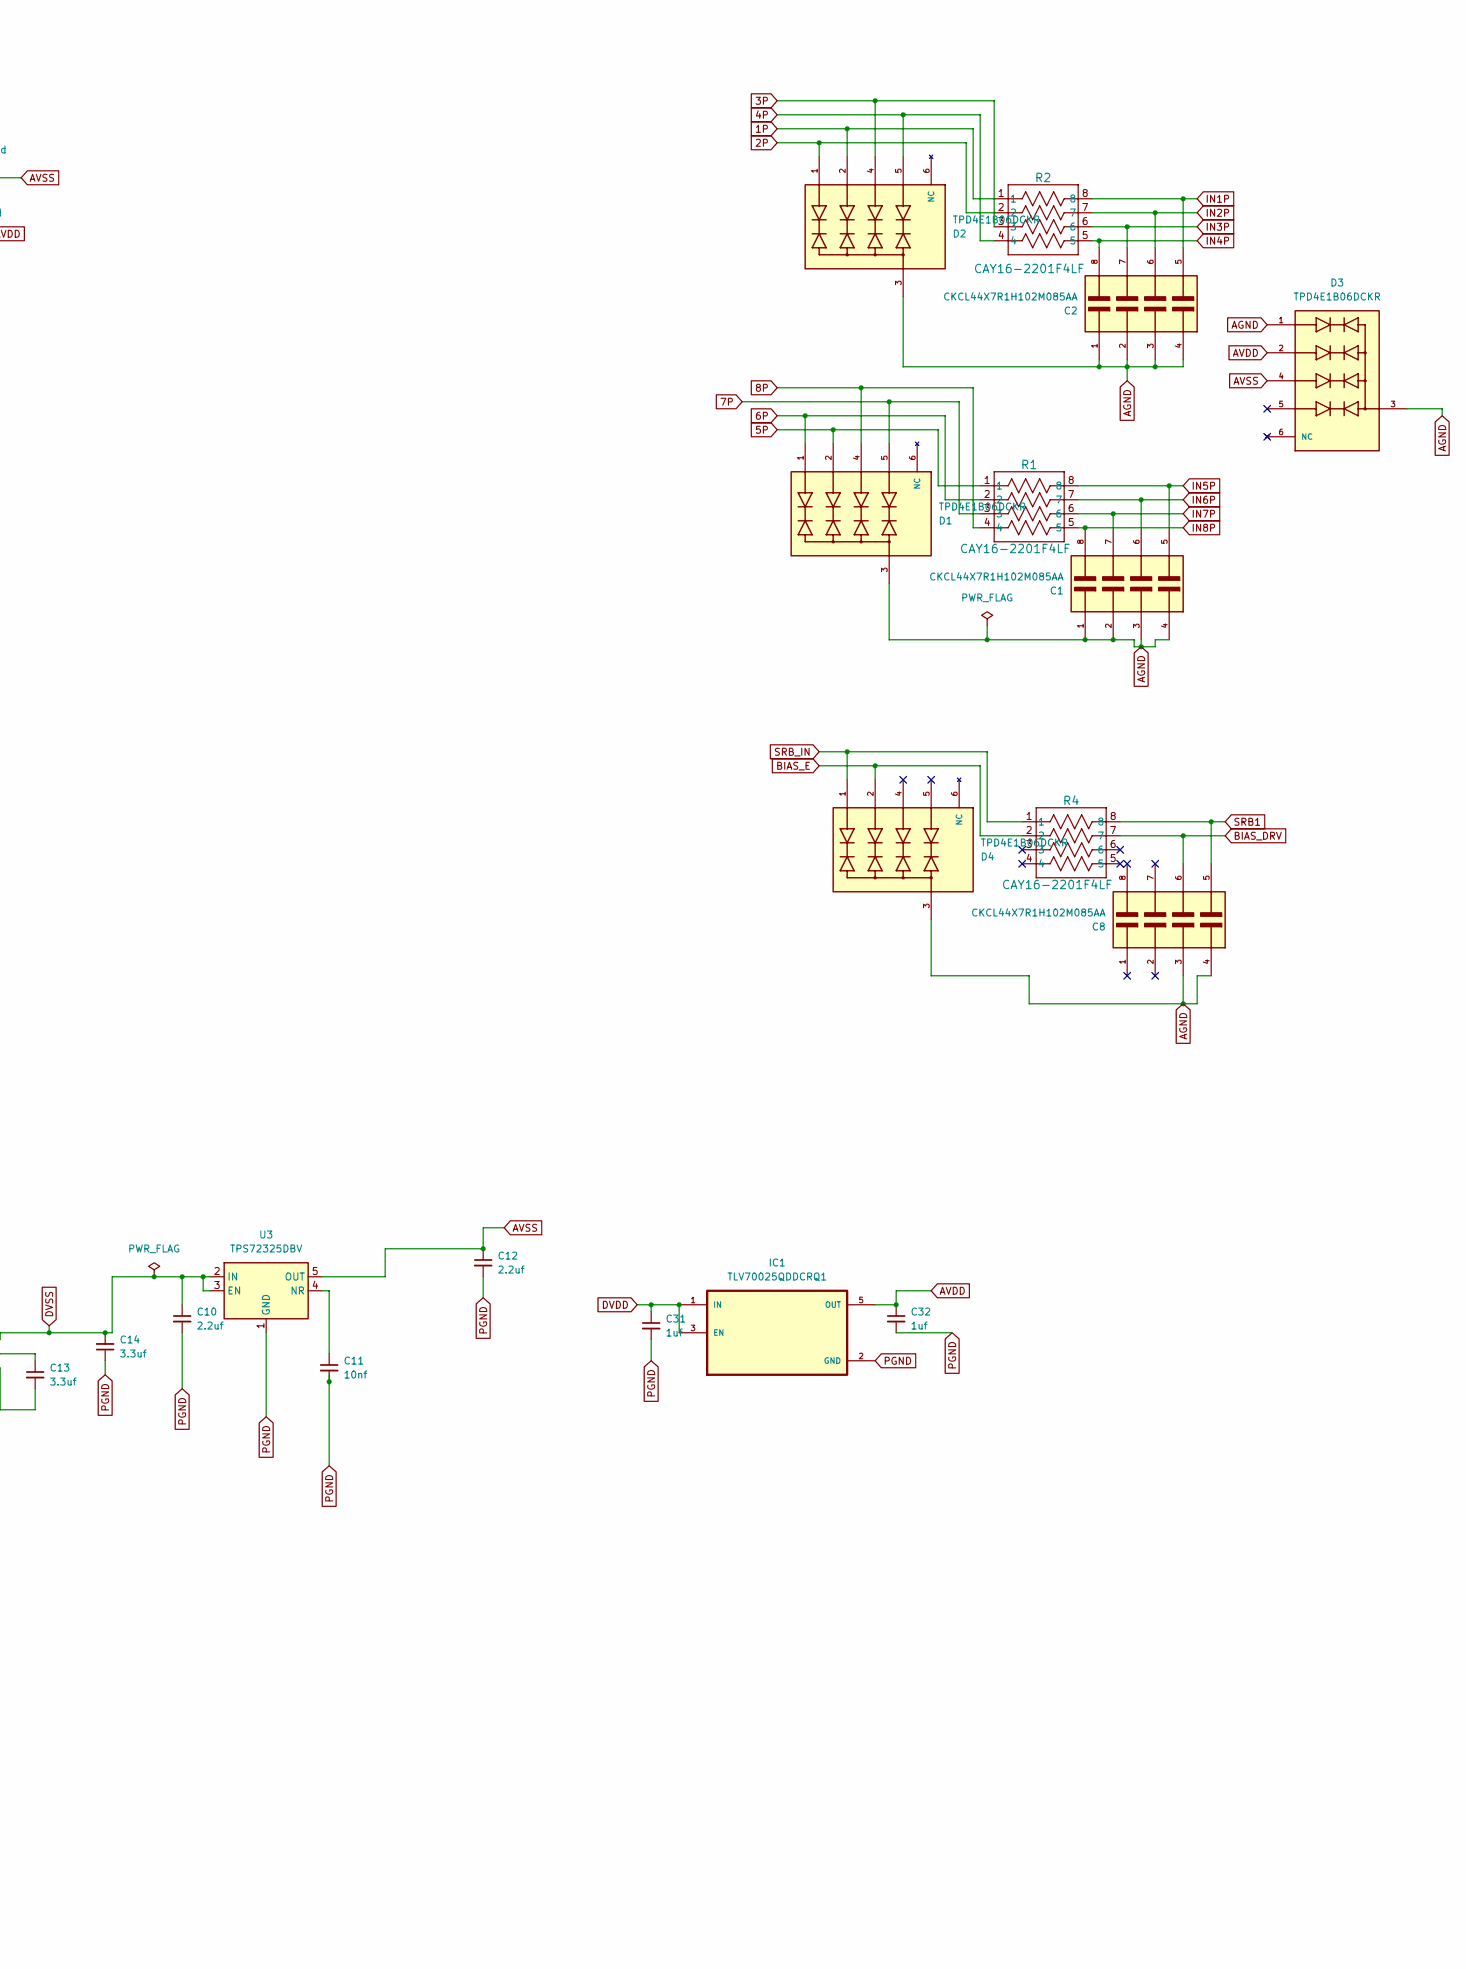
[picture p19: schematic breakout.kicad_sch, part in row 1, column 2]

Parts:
C1, C2, C8: CKCL44X7R1H102M085AA; W3A41C102MAT2A; PARTREV Dec 2014
C3, C4, C5, C6, C7, C16, C17, C18, C21, C22, C24, C26, C28, C29, C31, C32, C40, C42, C44: 1uf; C_0603_1608Metric_Pad1.08x0.95mm_HandSolder
C10, C12: 2.2uf; C_0603_1608Metric_Pad1.08x0.95mm_HandSolder
C11: 10nf; C_0603_1608Metric_Pad1.08x0.95mm_HandSolder
C13, C14: 3.3uf; CP_EIA-3216-18_Kemet-A_Pad1.58x1.35mm_HandSolder
C19: 100uf; C_1206_3216Metric_Pad1.33x1.80mm_HandSolder
C20: 10uf; CP_EIA-3216-18_Kemet-A_Pad1.58x1.35mm_HandSolder
C23, C27, C30, C39, C41, C43, C45: 0.1uf; C_0603_1608Metric_Pad1.08x0.95mm_HandSolder
C25, C46: 1.5nf; C_0603_1608Metric_Pad1.08x0.95mm_HandSolder
D1, D2, D3, D4: TPD4E1B06DCKR; TVS_TPD4E1B06DCKR; PARTREV C
FB1, FB2, FB3, FB4, FB5, FB6, FB7, FB9, FB10, FB11: FerriteBead; L_0603_1608Metric_Pad1.05x0.95mm_HandSolder
H1, H2, H3, H4: MountingHole; MountingHole_3.2mm_M3
IC1: TLV70025QDDCRQ1; SOT95P280X110-5N
J1: Conn_01x10_Pin; PinHeader_1x10_P2.54mm_Vertical
J2, J3: Conn_01x08_Pin; PinHeader_1x08_P2.54mm_Vertical
J4: Conn_01x08_Socket; PinSocket_1x08_P2.54mm_Vertical
J5: Conn_01x02_Socket; PinSocket_1x02_P2.54mm_Vertical
R1, R2, R4: CAY16-2201F4LF; CAY16_BRN
R3: 277; R_0603_1608Metric_Pad0.98x0.95mm_HandSolder
R6, R8, R9, R10: 10K; R_0603_1608Metric_Pad0.98x0.95mm_HandSolder
R7, R17: 1M; R_0603_1608Metric_Pad0.98x0.95mm_HandSolder
U1: AP2112K-3.3; SOT95P285X140-5N
U3: TPS72325DBV; SOT95P280X145-5N
U4: LM2665M6; SOT95P280X145-6N
U5: ADS1299IPAG; QFP50P1200X1200X120-64N

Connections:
1P: D2.2, J4.1, R2.1
2P: D2.1, J4.2, R2.2
3P: D2.4, J4.3, R2.3
4P: D2.5, J4.4, R2.4
5P: D1.2, J4.5, R1.1
6P: D1.1, J4.6, R1.2
7P: D1.5, J4.7, R1.3
8P: D1.4, J4.8, R1.4
AGND: C1.1, C1.2, C1.3, C1.4, C2.1, C2.2, C2.3, C2.4, C8.3, C8.4, C22.2, C27.2, C28.2, C29.2, C30.2, C39.2, C40.2, C42.1, C43.1, C44.1, C45.1, D1.3, D2.3, D3.1, D3.3, D4.3, FB5.2, FB7.1, FB9.1, FB10.2, FB11.2, U5.53 (AVSS1)
AVDD: C32.1, D3.2, FB1.2, FB3.1, IC1.5 (OUT)
AVSS: C12.1, D3.4, FB2.1, FB4.2, U3.5 (OUT)
BIAS_DRV: C8.6, R3.2, R4.7
BIAS_E: D4.2, J5.2, R4.2
CS: J1.8, U5.39 (*CS)
DGND: C24.1, FB6.2, FB7.2, FB9.2, J1.4, R6.2, R8.1, R9.2, R10.2, U5.31 (RESV1), U5.33 (DGND), U5.41 (DAISY_IN), U5.49 (DGND), U5.51 (DGND)
DIN: J1.7, U5.34 (DIN)
DOUT: J1.6, U5.43 (DOUT)
DRDY: J2.3, U5.47 (*DRDY)
DVDD: C7.1, C24.2, C31.1, IC1.1 (IN), IC1.3 (EN), U1.5 (VOUT), U4.1 (V+), U4.4 (SD), U5.35 (*PWDN), U5.48 (DVDD), U5.50 (DVDD), U5.52 (CLKSEL)
DVSS: C10.1, C14.2, U3.2 (IN), U3.3 (EN), U4.5 (OUT)
IN1P: C2.5, R2.8, U5.16 (IN1P)
IN2P: C2.6, R2.7, U5.14 (IN2P)
IN3P: C2.7, R2.6, U5.12 (IN3P)
IN4P: C2.8, R2.5, U5.10 (IN4P)
IN5P: C1.5, R1.8, U5.8 (IN5P)
IN6P: C1.6, R1.7, U5.6 (IN6P)
IN7P: C1.7, R1.6, U5.4 (IN7P)
IN8P: C1.8, R1.5, U5.2 (IN8P)
unnamed: C3.1, C5.2, C17.1, C44.2, C45.2, FB1.1, U5.19 (AVDD), U5.21 (AVDD), U5.22 (AVDD)
unnamed: C4.1, C21.1, C23.1, C26.1, C42.2, C43.2, FB2.2, U5.57 (AVSS), U5.58 (AVSS)
unnamed: C4.2, C21.2, C29.1, C30.1, FB3.2, U5.56 (AVDD), U5.59 (AVDD)
unnamed: C11.1, U3.4 (NR)
unnamed: C13.1, U4.6 (CAP+)
unnamed: C13.2, U4.3 (CAP-)
unnamed: C22.1, U5.54 (AVDD1)
unnamed: C46.1, R17.2, U5.62 (BIASIN)
unnamed: C25.2, R7.2, U5.61 (BIASINV)
unnamed: C25.1, C46.2, R3.1, R7.1, R17.1, U5.63 (BIASOUT)
unnamed: R8.2, U5.42 (GPIO1)
unnamed: R10.1, U5.44 (GPIO2)
unnamed: R6.1, U5.45 (GPIO3)
unnamed: R9.1, U5.46 (GPIO4)
unnamed: C19.2, U5.28 (VCAP1)
unnamed: C18.2, U5.30 (VCAP2)
unnamed: C23.2, C26.2, U5.55 (VCAP3)
unnamed: C16.2, U5.26 (VCAP4)
unnamed: C3.2, C5.1, C16.1, C17.2, C18.1, C19.1, C20.2, C27.1, C28.1, C39.1, C40.1, C41.2, FB4.1, U5.20 (AVSS), U5.23 (AVSS), U5.25 (VREFN), U5.32 (AVSS)
unnamed: C20.1, C41.1, U5.24 (VREFP)
PGND: C6.2, C7.2, C10.2, C11.2, C12.2, C14.1, C31.2, C32.2, FB5.1, FB6.1, FB10.1, FB11.1, IC1.2 (GND), J3.6, J3.7, U1.2 (GND), U3.1 (GND), U4.2 (GND)
RESET: J2.2, U5.36 (*RESET)
SCLK: J1.5, U5.40 (SCLK)
SRB1: C8.5, R4.8, U5.1 (IN8N), U5.3 (IN7N), U5.5 (IN6N), U5.7 (IN5N), U5.9 (IN4N), U5.11 (IN3N), U5.13 (IN2N), U5.15 (IN1N), U5.17 (SRB1)
SRB_IN: D4.1, J5.1, R4.1
START: J2.1, U5.38 (START)
VDD: C6.1, J3.5, U1.1 (VIN), U1.3 (EN)

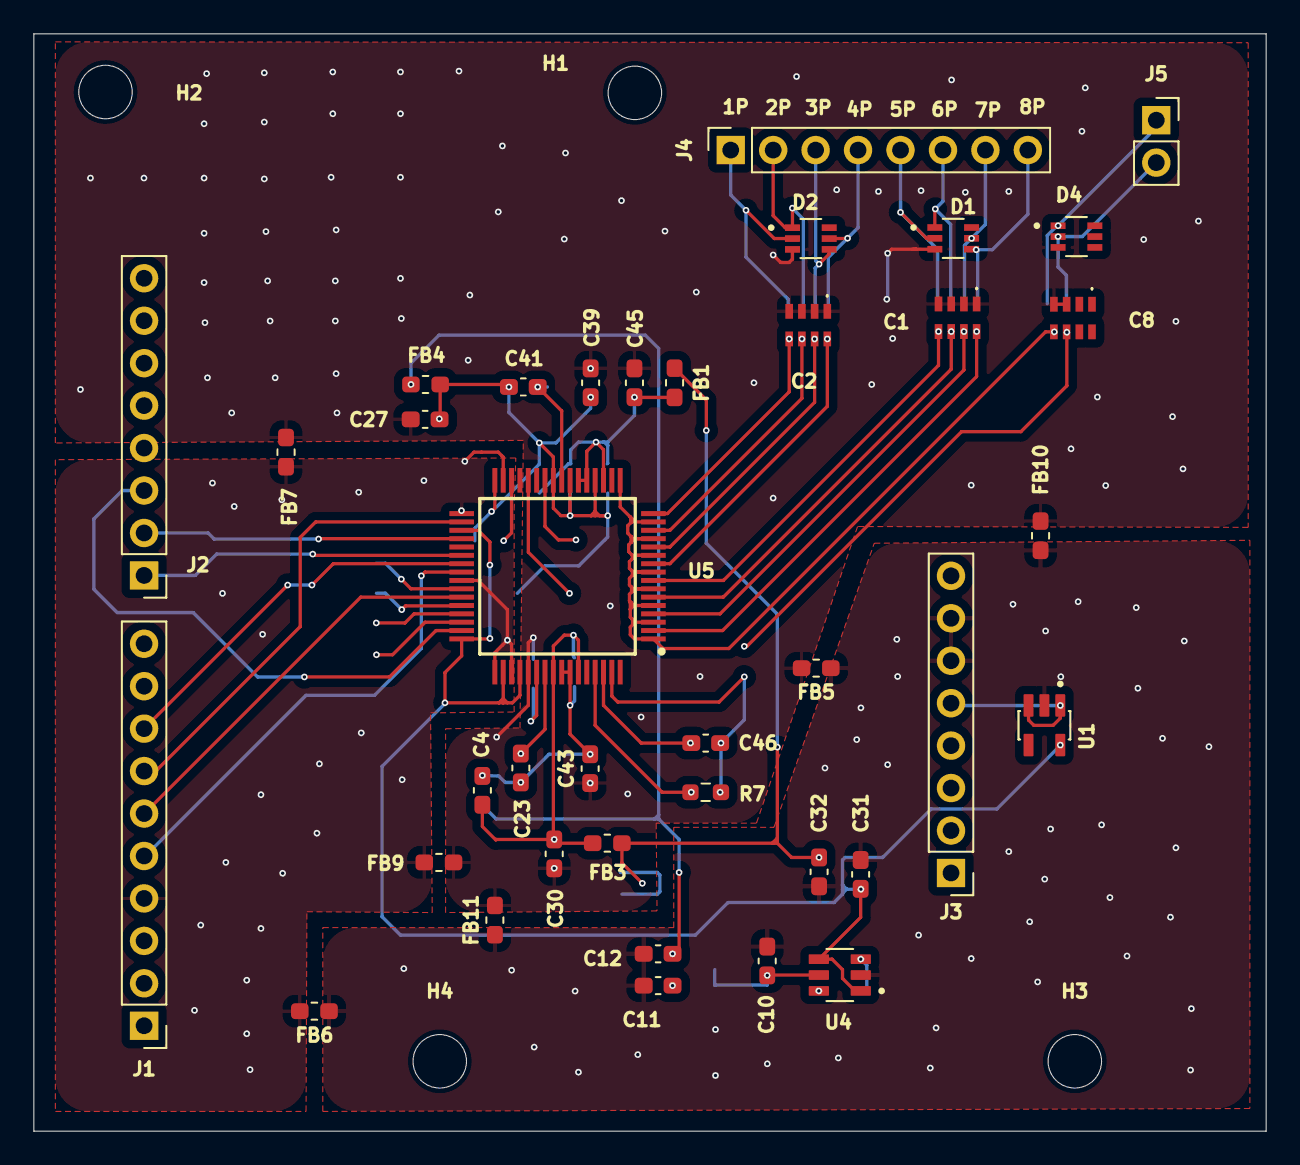
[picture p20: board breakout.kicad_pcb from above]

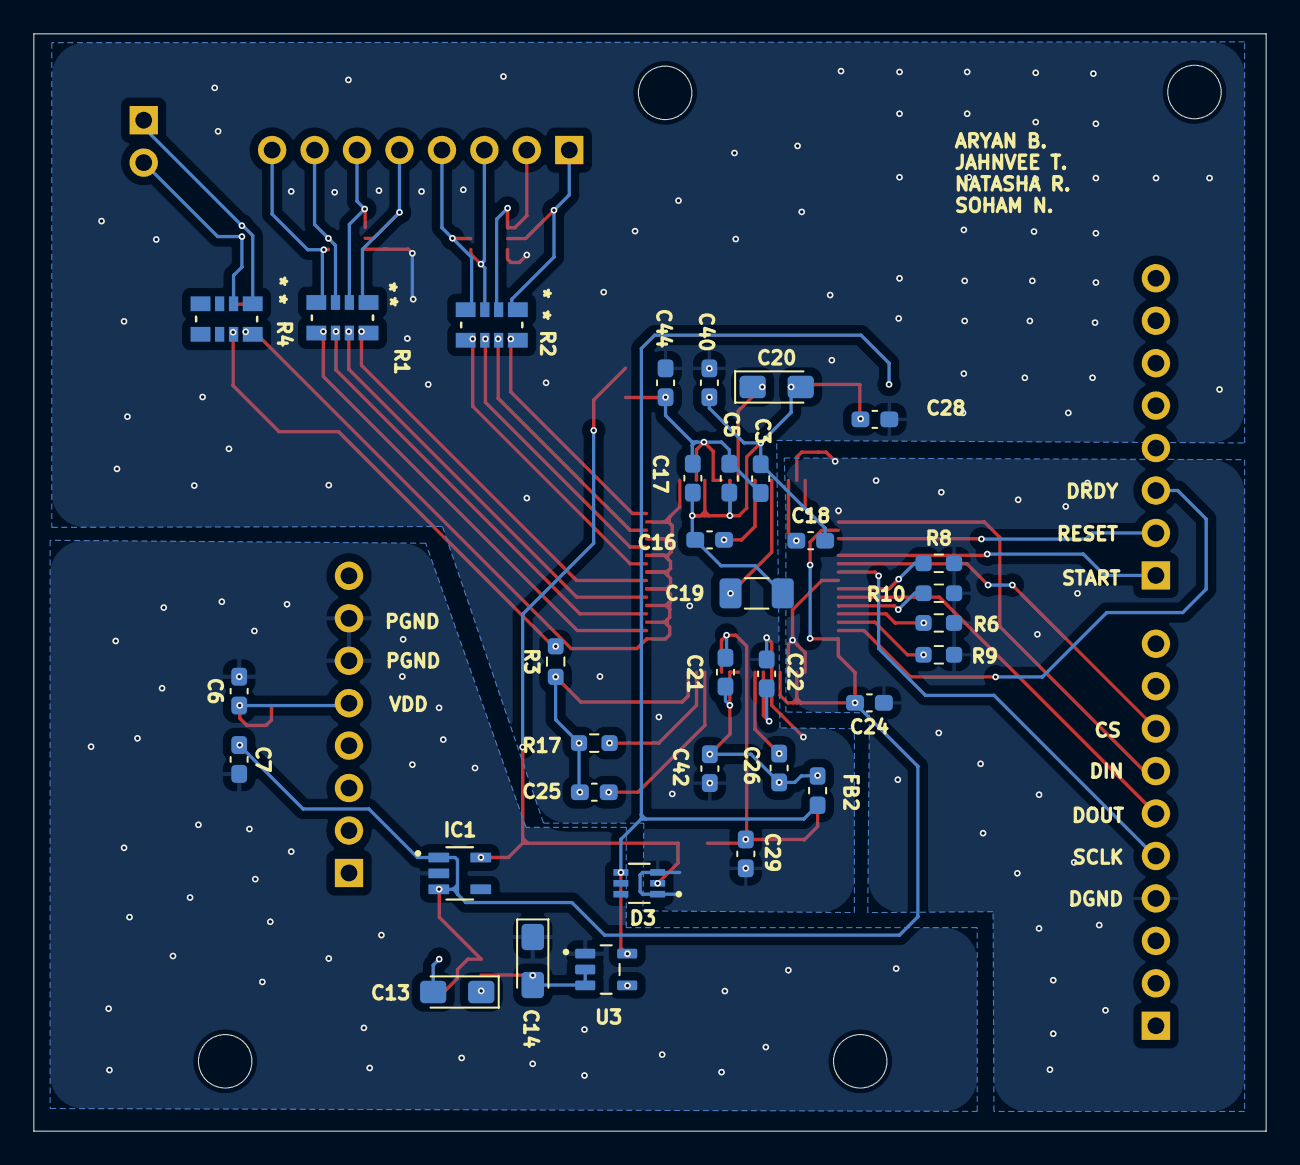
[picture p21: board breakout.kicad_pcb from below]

Board: 2 copper layers, 73.7 x 65.7 mm, 76 parts (34 on the bottom side), 55 nets.

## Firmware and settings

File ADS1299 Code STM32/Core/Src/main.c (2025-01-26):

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
/* Includes ------------------------------------------------------------------*/
#include "main.h"

/* USER CODE BEGIN Includes */
//#define CS_Pin GPIO_PIN_6  // Example pin number, replace with your actual pin number
//#define RESET_Pin GPIO_PIN_7  // Example pin number, replace with your actual pin number
//#define DRDY_Pin GPIO_PIN_9  // Example pin number, replace with your actual pin number
/* USER CODE END Includes */

SPI_HandleTypeDef hspi1;

UART_HandleTypeDef huart2;

void SystemClock_Config(void);
static void MX_GPIO_Init(void);
static void MX_USART2_UART_Init(void);
static void MX_SPI1_Init(void);
/* USER CODE BEGIN PFP */

#define SYSTICKCLOCK 16000000ULL // System clock frequency (8MHz)
#define SYSTICKPERUS (SYSTICKCLOCK / 1000000UL) // SysTick timer counts per microsecond

//static void delay_us(unsigned delay) __attribute__((always_inline));
//
//static void __attribute__((always_inline)) delay_us(unsigned delay) {
//    uint32_t ticks = SYSTICKPERUS * delay;
//    uint32_t start_tick = SysTick->VAL;
//
//    while(SysTick->VAL - start_tick < ticks);
//}
//__attribute__((always_inline))
void delay_try(unsigned delay){
	int i=0;
	for(i=0; i<delay; i++){
		__NOP();
	}
}
uint8_t rreg_command(uint8_t buffer1, uint8_t buffer2){
	HAL_GPIO_WritePin(GPIOB, GPIO_PIN_6, GPIO_PIN_RESET);
	uint8_t device;
	  //delay_try(10);
//	uint8_t buffer1_x = 0x20 | buffer1;
//	uint8_t buffer2_x = 0x00;
	  HAL_SPI_Transmit(&hspi1, (uint8_t *)&buffer1, 1, 0x1000);   //MOSI
	  delay_try(2);//delay 4 t_clk
	  HAL_SPI_Transmit(&hspi1, (uint8_t *)&buffer2, 1, 0x1000);  //MOSI
	  delay_try(2);//delay 4 t_clk
	  HAL_SPI_Receive(&hspi1, (uint8_t *)&device, 1, 0x1000);
	  delay_try(10);
	 HAL_GPIO_WritePin(GPIOB, GPIO_PIN_6, GPIO_PIN_SET);

	return device;
}


void wrreg_command(uint8_t reg_addr, uint8_t val_hex){
   HAL_GPIO_WritePin(GPIOB, GPIO_PIN_6, GPIO_PIN_RESET);
   uint8_t adress = 0x40|reg_addr;
   uint8_t dummy1 = 0x00;
   HAL_SPI_Transmit(&hspi1, (uint8_t*)&adress, 1, 0x1000);
   HAL_SPI_Transmit(&hspi1, (uint8_t*)&dummy1, 1, 0x1000);
   HAL_SPI_Transmit(&hspi1, (uint8_t*)&val_hex, 1, 0x1000);
   delay_try(100);
   HAL_GPIO_WritePin(GPIOB, GPIO_PIN_6, GPIO_PIN_SET);
}

/* USER CODE END PFP */

/* USER CODE BEGIN 0 */

//void spi_transmit_byte(uint8_t* data, int size){
//	int i=0;
//	for(i=0; i<size; i++){
//		HAL_SPI_Transmit(&hspi1, data[i], 1, HAL_MAX_DELAY);
//		delay_us(2);
//	}
//	return;
//}
//
//uint8_t spi_transmit_receive(uint8_t* address, int size, int outp_size){
//	int i=0;
//	uint8_t data_req[outp_size];
//	for(i=0; i<size; i++){
//		HAL_SPI_Transmit(&hspi1, address[i], 1, HAL_MAX_DELAY);
//		delay_us(2);
//	}
//	HAL_SPI_Receive(&hspi1, data_req, outp_size, HAL_MAX_DELAY);
//	return data_req;
//}


/* USER CODE END 0 */

/**
  * @brief  The application entry point.
  * @retval int
  */
int main(void)
{
  /* USER CODE BEGIN 1 */
//	uint8_t spi_buf[2];
//	uint8_t* value[27];
  /* USER CODE END 1 */

  /* MCU Configuration--------------------------------------------------------*/

  /* Reset of all peripherals, Initializes the Flash interface and the Systick. */
    HAL_Init();

  /* Configure the system clock */
  SystemClock_Config();

  /* Initialize all configured peripherals */
  MX_GPIO_Init();
  MX_USART2_UART_Init();
  MX_SPI1_Init();
  /* USER CODE BEGIN 2 */

  	uint8_t sdatac = 0x11;
	uint8_t buf1 = 0x20;
	uint8_t start = 0x08;
	uint8_t rdatac = 0x10;
	uint8_t rdata = 0x12;
	uint8_t buffer2 = 0x00;
	uint8_t rst = 0x06;

	uint8_t config1 = 0x01;
	uint8_t config2 = 0x02;
	uint8_t config3 = 0x03;
	uint8_t loff = 0x04;
	uint8_t ch1set = 0x05;
	uint8_t ch2set = 0x06;
	uint8_t ch3set = 0x07;
	uint8_t ch4set = 0x08;
	uint8_t ch5set = 0x09;
	uint8_t ch6set = 0x0A;
	uint8_t ch7set = 0x0B;
	uint8_t ch8set = 0x0C;
	uint8_t bias_sensp = 0x0D;
	uint8_t bias_sensn = 0x0E;
	uint8_t loff_sensp = 0x0F;
	uint8_t loff_sensn = 0x10;
	uint8_t loff_flip = 0x11;
	uint8_t loff_statp = 0x12;
	uint8_t loff_statn = 0x13;
	uint8_t gpio = 0x14;
	uint8_t misc1 = 0x15;
	uint8_t misc2 = 0x16;
	uint8_t config4 = 0x17;

  delay_try(100);
///////////////////////////////////////////////////////////////////////////////////////////////////////////////////////////////////////////
  HAL_GPIO_WritePin(GPIOB, GPIO_PIN_6, GPIO_PIN_RESET);
 // HAL_GPIO_WritePin(GPIOA, GPIO_PIN_8, GPIO_PIN_SET);

  HAL_GPIO_WritePin(GPIOB, GPIO_PIN_10, GPIO_PIN_SET);
  delay_try(50);
  HAL_GPIO_WritePin(GPIOB, GPIO_PIN_6, GPIO_PIN_SET);

  delay_try(10);

  HAL_GPIO_WritePin(GPIOB, GPIO_PIN_6, GPIO_PIN_RESET);
  delay_try(4);
  HAL_SPI_Transmit(&hspi1, (uint8_t*)&rst, 1, 0x1000);
  delay_try(100);
  HAL_GPIO_WritePin(GPIOB, GPIO_PIN_6, GPIO_PIN_SET);

  HAL_GPIO_WritePin(GPIOB, GPIO_PIN_6, GPIO_PIN_RESET);
  delay_try(4);
  HAL_SPI_Transmit(&hspi1, (uint8_t *)&sdatac, 1, 0x1000);
  delay_try(100);
  HAL_GPIO_WritePin(GPIOB, GPIO_PIN_6, GPIO_PIN_SET);

  delay_try(100);
/////////////////////////////////////////////////////////////////////////////////////////////////////////////////////////////////////////////
// uint8_t dum = 0x00;


//  HAL_GPIO_WritePin(GPIOB, GPIO_PIN_6, GPIO_PIN_RESET);
//
//  delay_try(10);
//  HAL_SPI_Transmit(&hspi1, (uint8_t *)&buffer1, 1, 0x1000);   //MOSI
//  delay_try(2);//delay 4 t_clk
//  HAL_SPI_Transmit(&hspi1, (uint8_t *)&buffer2, 1, 0x1000);  //MOSI
//  delay_try(2);//delay 4 t_clk
//  HAL_SPI_Receive(&hspi1, (uint8_t *)&device, 1, 0x1000);    //MISO
//
    uint8_t buffer1;

  	buffer1 = buf1 | 0x00;
    uint8_t read_byte = rreg_command(buffer1, buffer2);
    uint8_t dev_id[] = "Device Id is : ";
    HAL_UART_Transmit(&huart2, dev_id, sizeof(dev_id) - 1, 0x1000); // -1 to exclude null terminator
    char ads[16];
    sprintf(ads, "%u\r\n", read_byte); // Dereference the pointer to get the value
    HAL_UART_Transmit(&huart2, (uint8_t *)&ads, strlen(ads), 0x1000);

    buffer1 = buf1 | config1;
    read_byte = rreg_command(buffer1, buffer2);
    uint8_t c1[] = "Config1 is : ";
    HAL_UART_Transmit(&huart2, c1, sizeof(c1) - 1, 0x1000); // -1 to exclude null terminator
    sprintf(ads, "%u\r\n", read_byte); // Dereference the pointer to get the value
    HAL_UART_Transmit(&huart2, (uint8_t *)&ads, strlen(ads), 0x1000);

    buffer1 = buf1 | config2;
    read_byte = rreg_command(buffer1, buffer2);
	uint8_t c2[] = "Config2 is : ";
	HAL_UART_Transmit(&huart2, c2, sizeof(c2) - 1, 0x1000); // -1 to exclude null terminator
	sprintf(ads, "%u\r\n", read_byte); // Dereference the pointer to get the value
	HAL_UART_Transmit(&huart2, (uint8_t *)&ads, strlen(ads), 0x1000);

	buffer1 = buf1 | config3;
	read_byte = rreg_command(buffer1, buffer2);
	uint8_t c3[] = "Config3 is : ";
	HAL_UART_Transmit(&huart2, c3, sizeof(c3) - 1, 0x1000); // -1 to exclude null terminator
	sprintf(ads, "%u\r\n", read_byte); // Dereference the pointer to get the value
	HAL_UART_Transmit(&huart2, (uint8_t *)&ads, strlen(ads), 0x1000);

	buffer1 = buf1 | loff;
	read_byte = rreg_command(buffer1, buffer2);
	uint8_t c4[] = "LOFF is : ";
	HAL_UART_Transmit(&huart2, c4, sizeof(c4) - 1, 0x1000); // -1 to exclude null terminator
	sprintf(ads, "%u\r\n", read_byte); // Dereference the pointer to get the value
	HAL_UART_Transmit(&huart2, (uint8_t *)&ads, strlen(ads), 0x1000);

	buffer1 = buf1 | ch1set;
	read_byte = rreg_command(buffer1, buffer2);
	uint8_t c5[] = "Channel 1 Register is : ";
	HAL_UART_Transmit(&huart2, c5, sizeof(c5) - 1, 0x1000); // -1 to exclude null terminator
	sprintf(ads, "%u\r\n", read_byte); // Dereference the pointer to get the value
	HAL_UART_Transmit(&huart2, (uint8_t *)&ads, strlen(ads), 0x1000);

	buffer1 = buf1 | bias_sensp;
	read_byte = rreg_command(buffer1, buffer2);
	uint8_t c6[] = "Bias_sensep is : ";
	HAL_UART_Transmit(&huart2, c6, sizeof(c6) - 1, 0x1000); // -1 to exclude null terminator
	sprintf(ads, "%u\r\n", read_byte); // Dereference the pointer to get the value
	HAL_UART_Transmit(&huart2, (uint8_t *)&ads, strlen(ads), 0x1000);

	buffer1 = buf1 | bias_sensn;
	read_byte = rreg_command(buffer1, buffer2);
	uint8_t c7[] = "Bias_sensen is : ";
	HAL_UART_Transmit(&huart2, c7, sizeof(c7) - 1, 0x1000); // -1 to exclude null terminator
	sprintf(ads, "%u\r\n", read_byte); // Dereference the pointer to get the value
	HAL_UART_Transmit(&huart2, (uint8_t *)&ads, strlen(ads), 0x1000);

	buffer1 = buf1 |loff_sensp;
	read_byte = rreg_command(buffer1, buffer2);
	uint8_t c8[] = "loff_sensep is : ";
	HAL_UART_Transmit(&huart2, c8, sizeof(c8) - 1, 0x1000); // -1 to exclude null terminator
	sprintf(ads, "%u\r\n", read_byte); // Dereference the pointer to get the value
	HAL_UART_Transmit(&huart2, (uint8_t *)&ads, strlen(ads), 0x1000);

	buffer1 = buf1 | loff_sensn;
	read_byte = rreg_command(buffer1, buffer2);
	uint8_t c9[] = "loff_sensen is : ";
	HAL_UART_Transmit(&huart2, c9, sizeof(c9) - 1, 0x1000); // -1 to exclude null terminator
	sprintf(ads, "%u\r\n", read_byte); // Dereference the pointer to get the value
	HAL_UART_Transmit(&huart2, (uint8_t *)&ads, strlen(ads), 0x1000);

	buffer1 = buf1 | loff_flip;
	read_byte = rreg_command(buffer1, buffer2);
	uint8_t c10[] = "loff_flip is : ";
	HAL_UART_Transmit(&huart2, c10, sizeof(c10) - 1, 0x1000); // -1 to exclude null terminator
	sprintf(ads, "%u\r\n", read_byte); // Dereference the pointer to get the value
	HAL_UART_Transmit(&huart2, (uint8_t *)&ads, strlen(ads), 0x1000);

	buffer1 = buf1 | loff_statp;
	read_byte = rreg_command(buffer1, buffer2);
	uint8_t c11[] = "loff_statp is : ";
	HAL_UART_Transmit(&huart2, c11, sizeof(c11) - 1, 0x1000); // -1 to exclude null terminator
	sprintf(ads, "%u\r\n", read_byte); // Dereference the pointer to get the value
	HAL_UART_Transmit(&huart2, (uint8_t *)&ads, strlen(ads), 0x1000);

	buffer1 = buf1 | loff_statn;
	read_byte = rreg_command(buffer1, buffer2);
	uint8_t c12[] = "loff_statn is : ";
	HAL_UART_Transmit(&huart2, c12, sizeof(c12) - 1, 0x1000); // -1 to exclude null terminator
	sprintf(ads, "%u\r\n", read_byte); // Dereference the pointer to get the value
	HAL_UART_Transmit(&huart2, (uint8_t *)&ads, strlen(ads), 0x1000);

	buffer1 = buf1 | gpio;
	read_byte = rreg_command(buffer1, buffer2);
	uint8_t c13[] = "gpio is : ";
	HAL_UART_Transmit(&huart2, c13, sizeof(c13) - 1, 0x1000); // -1 to exclude null terminator
	sprintf(ads, "%u\r\n", read_byte); // Dereference the pointer to get the value
	HAL_UART_Transmit(&huart2, (uint8_t *)&ads, strlen(ads), 0x1000);

	buffer1 = buf1 | misc1;
	read_byte = rreg_command(buffer1, buffer2);
	uint8_t c14[] = "misc1 is : ";
	HAL_UART_Transmit(&huart2, c14, sizeof(c14) - 1, 0x1000); // -1 to exclude null terminator
	sprintf(ads, "%u\r\n", read_byte); // Dereference the pointer to get the value
	HAL_UART_Transmit(&huart2, (uint8_t *)&ads, strlen(ads), 0x1000);

	buffer1 = buf1 | misc2;
	read_byte = rreg_command(buffer1, buffer2);
	uint8_t c15[] = "misc2 is : ";
	HAL_UART_Transmit(&huart2, c15, sizeof(c15) - 1, 0x1000); // -1 to exclude null terminator
	sprintf(ads, "%u\r\n", read_byte); // Dereference the pointer to get the value
	HAL_UART_Transmit(&huart2, (uint8_t *)&ads, strlen(ads), 0x1000);

	buffer1 = buf1 | config4;
	read_byte = rreg_command(buffer1, buffer2);
	uint8_t c16[] = "config4 is : ";
	HAL_UART_Transmit(&huart2, c16, sizeof(c16) - 1, 0x1000); // -1 to exclude null terminator
	sprintf(ads, "%u\r\n", read_byte); // Dereference the pointer to get the value
	HAL_UART_Transmit(&huart2, (uint8_t *)&ads, strlen(ads), 0x1000);

//	HAL_Delay(1000);
  delay_try(100);
///////////////////////////////////////////////////////////////////////////////////////////////////////////////////////////////////////////
	wrreg_command(config1, 0xD5); //D5
	wrreg_command(config2, 0xC0);// D1
	wrreg_command(config3, 0xEF);// E4, E0, E6
	wrreg_command(loff, 0x00);//80
	wrreg_command(ch1set, 0x00);//55
	wrreg_command(ch2set, 0x00);
	wrreg_command(ch3set, 0x00);
	wrreg_command(ch4set, 0x00);
	wrreg_command(ch5set, 0x00);
	wrreg_command(ch6set, 0x00);
	wrreg_command(ch7set, 0x00);
	wrreg_command(ch8set, 0x00);
	wrreg_command(bias_sensp, 0x00);//FF
	wrreg_command(bias_sensn, 0x00);//FF
	wrreg_command(loff_sensp, 0x00);//FF
	wrreg_command(loff_sensn, 0x00);//FF
	wrreg_command(loff_flip, 0x00);
	wrreg_command(gpio, 0x0F); //00, FF, F0
	wrreg_command(misc1, 0x20);
	wrreg_command(misc2, 0x00);
	wrreg_command(config4, 0x02); //00
///////////////////////////////////////////////////////////////////////////////////////////////////////////////////////////////////////////
//  read_byte = rreg_command(buffer1, buffer2);

		buffer1 = buf1 | 0x00;
	    read_byte = rreg_command(buffer1, buffer2);
//	    uint8_t dev_id[] = "Device Id is : ";
	    HAL_UART_Transmit(&huart2, dev_id, sizeof(dev_id) - 1, 0x1000); // -1 to exclude null terminator
//	     char ads[16];
		sprintf(ads, "%u\r\n", read_byte); // Dereference the pointer to get the value
	    HAL_UART_Transmit(&huart2, (uint8_t *)&ads, strlen(ads), 0x1000);

	    buffer1 = buf1 | config1;
	    read_byte = rreg_command(buffer1, buffer2);
//	    uint8_t c1[] = "Config1 is : ";
	    HAL_UART_Transmit(&huart2, c1, sizeof(c1) - 1, 0x1000); // -1 to exclude null terminator
		sprintf(ads, "%u\r\n", read_byte); // Dereference the pointer to get the value
	    HAL_UART_Transmit(&huart2, (uint8_t *)&ads, strlen(ads), 0x1000);

	    buffer1 = buf1 | config2;
	    read_byte = rreg_command(buffer1, buffer2);
//		uint8_t c2[] = "Config2 is : ";
		HAL_UART_Transmit(&huart2, c2, sizeof(c2) - 1, 0x1000); // -1 to exclude null terminator
		sprintf(ads, "%u\r\n", read_byte); // Dereference the pointer to get the value
		HAL_UART_Transmit(&huart2, (uint8_t *)&ads, strlen(ads), 0x1000);

		buffer1 = buf1 | config3;
		read_byte = rreg_command(buffer1, buffer2);
//		uint8_t c3[] = "Config3 is : ";
		HAL_UART_Transmit(&huart2, c3, sizeof(c3) - 1, 0x1000); // -1 to exclude null terminator
		sprintf(ads, "%u\r\n", read_byte); // Dereference the pointer to get the value
		HAL_UART_Transmit(&huart2, (uint8_t *)&ads, strlen(ads), 0x1000);

		buffer1 = buf1 | loff;
		read_byte = rreg_command(buffer1, buffer2);
//		uint8_t c4[] = "LOFF is : ";
		HAL_UART_Transmit(&huart2, c4, sizeof(c4) - 1, 0x1000); // -1 to exclude null terminator
		sprintf(ads, "%u\r\n", read_byte); // Dereference the pointer to get the value
		HAL_UART_Transmit(&huart2, (uint8_t *)&ads, strlen(ads), 0x1000);

		buffer1 = buf1 | ch1set;
		read_byte = rreg_command(buffer1, buffer2);
//		uint8_t c5[] = "Channel 1 Register is : ";
		HAL_UART_Transmit(&huart2, c5, sizeof(c5) - 1, 0x1000); // -1 to exclude null terminator
		sprintf(ads, "%u\r\n", read_byte); // Dereference the pointer to get the value
		HAL_UART_Transmit(&huart2, (uint8_t *)&ads, strlen(ads), 0x1000);

		buffer1 = buf1 | bias_sensp;
		read_byte = rreg_command(buffer1, buffer2);
//		uint8_t c6[] = "Bias_sensep is : ";
		HAL_UART_Transmit(&huart2, c6, sizeof(c6) - 1, 0x1000); // -1 to exclude null terminator
		sprintf(ads, "%u\r\n", read_byte); // Dereference the pointer to get the value
		HAL_UART_Transmit(&huart2, (uint8_t *)&ads, strlen(ads), 0x1000);

		buffer1 = buf1 | bias_sensn;
		read_byte = rreg_command(buffer1, buffer2);
//		uint8_t c7[] = "Bias_sensen is : ";
		HAL_UART_Transmit(&huart2, c7, sizeof(c7) - 1, 0x1000); // -1 to exclude null terminator
		sprintf(ads, "%u\r\n", read_byte); // Dereference the pointer to get the value
		HAL_UART_Transmit(&huart2, (uint8_t *)&ads, strlen(ads), 0x1000);

		buffer1 = buf1 |loff_sensp;
		read_byte = rreg_command(buffer1, buffer2);
//		uint8_t c8[] = "loff_sensep is : ";
		HAL_UART_Transmit(&huart2, c8, sizeof(c8) - 1, 0x1000); // -1 to exclude null terminator
		sprintf(ads, "%u\r\n", read_byte); // Dereference the pointer to get the value
		HAL_UART_Transmit(&huart2, (uint8_t *)&ads, strlen(ads), 0x1000);

		buffer1 = buf1 | loff_sensn;
		read_byte = rreg_command(buffer1, buffer2);
//		uint8_t c9[] = "loff_sensen is : ";
		HAL_UART_Transmit(&huart2, c9, sizeof(c9) - 1, 0x1000); // -1 to exclude null terminator
		sprintf(ads, "%u\r\n", read_byte); // Dereference the pointer to get the value
		HAL_UART_Transmit(&huart2, (uint8_t *)&ads, strlen(ads), 0x1000);

		buffer1 = buf1 | loff_flip;
		read_byte = rreg_command(buffer1, buffer2);
//		uint8_t c10[] = "loff_flip is : ";
		HAL_UART_Transmit(&huart2, c10, sizeof(c10) - 1, 0x1000); // -1 to exclude null terminator
		sprintf(ads, "%u\r\n", read_byte); // Dereference the pointer to get the value
		HAL_UART_Transmit(&huart2, (uint8_t *)&ads, strlen(ads), 0x1000);

		buffer1 = buf1 | loff_statp;
		read_byte = rreg_command(buffer1, buffer2);
//		uint8_t c11[] = "loff_statp is : ";
		HAL_UART_Transmit(&huart2, c11, sizeof(c11) - 1, 0x1000); // -1 to exclude null terminator
		sprintf(ads, "%u\r\n", read_byte); // Dereference the pointer to get the value
		HAL_UART_Transmit(&huart2, (uint8_t *)&ads, strlen(ads), 0x1000);

		buffer1 = buf1 | loff_statn;
		read_byte = rreg_command(buffer1, buffer2);
//		uint8_t c12[] = "loff_statn is : ";
		HAL_UART_Transmit(&huart2, c12, sizeof(c12) - 1, 0x1000); // -1 to exclude null terminator
		sprintf(ads, "%u\r\n", read_byte); // Dereference the pointer to get the value
		HAL_UART_Transmit(&huart2, (uint8_t *)&ads, strlen(ads), 0x1000);

		buffer1 = buf1 | gpio;
		read_byte = rreg_command(buffer1, buffer2);
//		uint8_t c13[] = "gpio is : ";
		HAL_UART_Transmit(&huart2, c13, sizeof(c13) - 1, 0x1000); // -1 to exclude null terminator
		sprintf(ads, "%u\r\n", read_byte); // Dereference the pointer to get the value
		HAL_UART_Transmit(&huart2, (uint8_t *)&ads, strlen(ads), 0x1000);

		buffer1 = buf1 | misc1;
		read_byte = rreg_command(buffer1, buffer2);
//		uint8_t c14[] = "misc1 is : ";
		HAL_UART_Transmit(&huart2, c14, sizeof(c14) - 1, 0x1000); // -1 to exclude null terminator
		sprintf(ads, "%u\r\n", read_byte); // Dereference the pointer to get the value
		HAL_UART_Transmit(&huart2, (uint8_t *)&ads, strlen(ads), 0x1000);

		buffer1 = buf1 | misc2;
		read_byte = rreg_command(buffer1, buffer2);
//		uint8_t c15[] = "misc2 is : ";
		HAL_UART_Transmit(&huart2, c15, sizeof(c15) - 1, 0x1000); // -1 to exclude null terminator
		sprintf(ads, "%u\r\n", read_byte); // Dereference the pointer to get the value
		HAL_UART_Transmit(&huart2, (uint8_t *)&ads, strlen(ads), 0x1000);

		buffer1 = buf1 | config4;
		read_byte = rreg_command(buffer1, buffer2);
//		uint8_t c16[] = "config4 is : ";
		HAL_UART_Transmit(&huart2, c16, sizeof(c16) - 1, 0x1000); // -1 to exclude null terminator
		sprintf(ads, "%u\r\n", read_byte); // Dereference the pointer to get the value
		HAL_UART_Transmit(&huart2, (uint8_t *)&ads, strlen(ads), 0x1000);


  delay_try(10);

//  HAL_GPIO_WritePin(GPIOA, GPIO_PIN_8, GPIO_PIN_RESET);
  delay_try(4);
  HAL_GPIO_WritePin(GPIOB, GPIO_PIN_6, GPIO_PIN_RESET);
  delay_try(4);
  HAL_GPIO_WritePin(GPIOA, GPIO_PIN_8, GPIO_PIN_SET);
//  HAL_SPI_Transmit(&hspi1, (uint8_t *)& , 1, 0x1000);
  delay_try(100);

  //send RDATAC command
//  delay_us(4);
  HAL_SPI_Transmit(&hspi1, (uint8_t *)&rdatac, 1, 0x1000);
  delay_try(4);
  //HAL_GPIO_WritePin(GPIOA, GPIO_PIN_8, GPIO_PIN_SET);

//  HAL_GPIO_WritePin(GPIOB, GPIO_PIN_6, GPIO_PIN_SET);
//  uint32_t read_dat;
//  while(1){

  uint8_t suc[] = "success";
  	uint32_t status_reg;
	uint8_t inbyte=0x00;
	status_reg = 0x00000000;
	uint32_t output[8];
	uint32_t dataPacket = 0x00000000;
	uint8_t dataByte;
//	uint8_t chan[] = "Channel:";
  while(1){
	  if(HAL_GPIO_ReadPin(GPIOB, GPIO_PIN_4) == 0){
		  //HAL_UART_Transmit(&huart2, suc, sizeof(suc) - 1, 0x1000);
		  for (int j = 0; j < 3; j++) {
			HAL_SPI_Receive(&hspi1, (uint8_t*)&inbyte, 1, 0x1000); // Pass the address of inbyte
			status_reg = (status_reg << 8) | inbyte;
		  }

		  for(int i = 0; i < 8; i++) {
			for(int j = 0; j < 3; j++) {
				HAL_SPI_Receive(&hspi1, (uint8_t*)&dataByte, 1, 0x1000); // Corrected variable name
				dataPacket = (dataPacket << 8) | dataByte;
			}
			output[i] = dataPacket;
			dataPacket = 0;
		}


//		  			char ads_data[16];
//		  			sprintf(ads_data, "%lu\r\n", status_reg);
////		  			printf("Status_reg: %s", ads_data);
//		  			HAL_UART_Transmit(&huart2, (uint8_t*)ads_data, strlen(ads_data), 0x1000);
//		  			for(int i = 0; i < 8; i++) {
//		  				HAL_UART_Transmit(&huart2, chan, sizeof(chan) - 1, 0x1000);
//
//		  				 sprintf(ads_data, "%lu\r\n", output[i]);
////		  				 printf("Channel : %s", ads_data);
//		  				 HAL_UART_Transmit(&huart2, (uint8_t*)ads_data, strlen(ads_data), 0x1000);
//
//		  			}
		  char ads_data[16];
		  	HAL_UART_Transmit(&huart2, suc, sizeof(suc) - 1, 0x1000);

		  	sprintf(ads_data, "%lu\r\n", status_reg);
		  //		  			printf("Status_reg: %s", ads_data);
		  	HAL_UART_Transmit(&huart2, (uint8_t*)ads_data, strlen(ads_data), 0x1000);
		  //	for(int i = 0; i < 8; i++) {
		  ////		HAL_UART_Transmit(&huart2, chan, sizeof(chan) - 1, 0x1000);

		  		 sprintf(ads_data, "%lu\r\n", output[4]);
		  //		  				 printf("Channel : %s", ads_data);
		  		 HAL_UART_Transmit(&huart2, (uint8_t*)ads_data, strlen(ads_data), 0x1000);

		  //	}
		  	delay_try(10000);
//		  			delay_try(1000);
//		 HAL_Delay(100);
		  		}
//	  else{
//		  continue;
//	  }
//	  char ads_data[16];
//	HAL_UART_Transmit(&huart2, suc, sizeof(suc) - 1, 0x1000);
//
//	sprintf(ads_data, "%lu\r\n", status_reg);
////		  			printf("Status_reg: %s", ads_data);
//	HAL_UART_Transmit(&huart2, (uint8_t*)ads_data, strlen(ads_data), 0x1000);
////	for(int i = 0; i < 8; i++) {
//////		HAL_UART_Transmit(&huart2, chan, sizeof(chan) - 1, 0x1000);
//
//		 sprintf(ads_data, "%lu\r\n", output[0]);
////		  				 printf("Channel : %s", ads_data);
//		 HAL_UART_Transmit(&huart2, (uint8_t*)ads_data, strlen(ads_data), 0x1000);
//
////	}
//	delay_try(10000);
  }
	  //  HAL_UART_Transmit(&huart2, channel, sizeof(channel) - 1, 0x1000); // -1 to exclude null terminator
////	    char ads_r[32*8];
////	    sprintf(ads_r, "%u\n", read_dat); // Dereference the pointer to get the value
////	    HAL_UART_Transmit(&huart2, (uint8_t *)&ads, strlen(ads), 0x1000);
//  }
  delay_try(4);
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

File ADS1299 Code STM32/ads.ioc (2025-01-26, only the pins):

Mcu.UserName=STM32F103RBTx
PA13.GPIO_Label=TMS
PA13.Signal=SYS_JTMS-SWDIO
PA14.GPIO_Label=TCK
PA14.Signal=SYS_JTCK-SWCLK
PA2.GPIO_Label=USART_TX
PA2.Signal=USART2_TX
PA3.GPIO_Label=USART_RX
PA3.Signal=USART2_RX
PA5.Signal=SPI1_SCK
PA6.Signal=SPI1_MISO
PA7.Signal=SPI1_MOSI
PA8.Signal=GPIO_Output
PB10.Signal=GPIO_Output
PB3.GPIO_Label=SWO
PB3.Signal=SYS_JTDO-TRACESWO
PB4.Signal=GPIO_Input
PB6.Signal=GPIO_Output
PC13-TAMPER-RTC.GPIO_Label=B1 [Blue PushButton]
PC13-TAMPER-RTC.Signal=GPXTI13
PC14-OSC32_IN.Signal=RCC_OSC32_IN
PC15-OSC32_OUT.Signal=RCC_OSC32_OUT
PD0-OSC_IN.Signal=RCC_OSC_IN
PD1-OSC_OUT.Signal=RCC_OSC_OUT

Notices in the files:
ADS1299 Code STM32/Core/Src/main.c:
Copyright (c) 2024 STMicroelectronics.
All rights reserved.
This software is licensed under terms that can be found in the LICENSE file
